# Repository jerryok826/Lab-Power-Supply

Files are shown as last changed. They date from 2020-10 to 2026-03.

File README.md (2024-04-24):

# Lab Power Supply
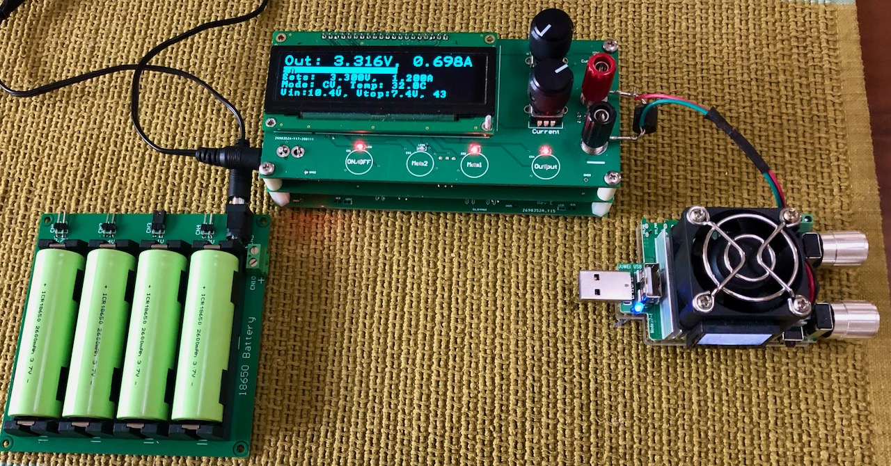
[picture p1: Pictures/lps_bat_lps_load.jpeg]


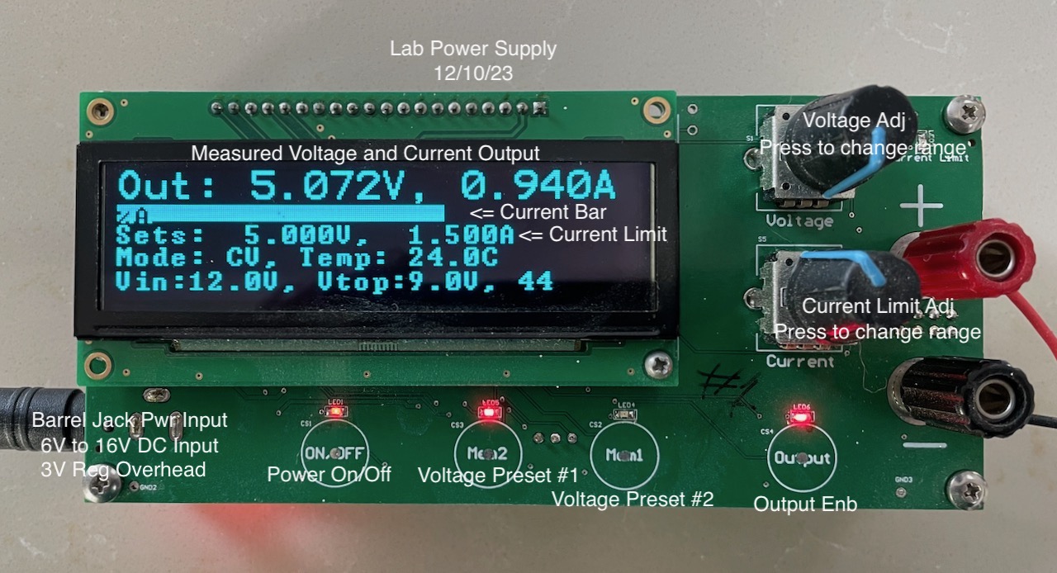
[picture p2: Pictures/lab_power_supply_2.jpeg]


## Project Description
I always thought that most laborary power supplies (LPS) take up to much bench space. This design is just 2.5 inches by 5.5 inches and runs off a wall wart or it can be powered from a lithium battery pack. The unit's specs are 0 to 15 volts output with a maximum output current of 1.5 amps. It has two output adjustable voltage presets with defaults of 5 and 3.3 volts. It has two rotary encoders, one for voltage control and the other for current limiting. Pressing an encoder button will change it's adjustement range. There is one additional button for output enable. The LPS can also be controlled remotely via USB using ModBus. There is also a realtime analog current bar graph on the oled display.

The control processor is a stm32f103c8t6, an Arm Cortex-M3 MCU with 64 Kbytes of flash memory and a 72 MHz CPU. The current code runs on libopencm3 and FreeRTOS. The display is a 256x128 OLED display. It is driven by uGui software. The unit is composed of two boards. The top board is the control and display board. The board below is the regulator board. The regulator board is composed of a low voltage drop linear regulator and a highly efficient switching regulator. Because of the combined efficiency of the switching and linear regulator not much of a heat sink is required. To reduce the noise generated by the switcher to a minimum, the switcher has large imput capacitors and a 3KHz loop pass filter on its output feeding the linear regulator. The switcher output voltage set to maintain a two voltage drop across the linear regulator.
### Project Status
The project is basically complete. I am working on converting the design to Kicad and STM32 IDE Cube. Also I'm thinking abouting redoing the display board with a RP2040 running MicroPython. This should make it easy for the end user to add their own features. For example, adding WIFI control support.

## Design Files
### Electrical Design Files
This project was initially designed with Altium Designer and is now being updated with Kicad 7.X The control software is C code runing on FreeRTOS.

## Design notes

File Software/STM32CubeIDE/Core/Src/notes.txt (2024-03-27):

notes.txt
~/STM32CubeIDE/workspace_1.14.0/lps_stm32f103RTC6_test1/Core/Src

cd ~/STM32CubeIDE/workspace_1.14.0/
tar -czvf lps_stm32f103RTC6_test1.tgz lps_stm32f103RTC6_test1
cd lps_stm32f103RTC6_test1/Core/Src

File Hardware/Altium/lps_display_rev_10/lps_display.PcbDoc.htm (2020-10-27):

Reporting Options

# File in Previous Format

Date | : | 7/23/2018
Time | : | 6:37:35 PM
Filename | : | C:\circuits\Projects\lab_power_supply\lab_pwr_supply.PcbDoc

Version | Warning

This file was generated by an earlier version of the software

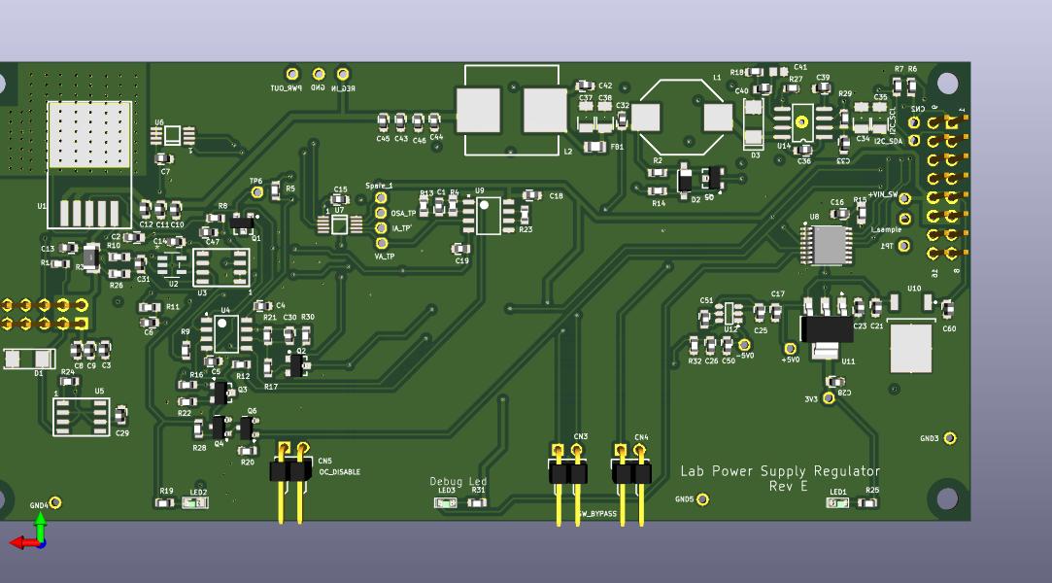
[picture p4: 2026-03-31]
Hardware/Kicad/lps_regulator/lps_regulator_rev_12.jpg

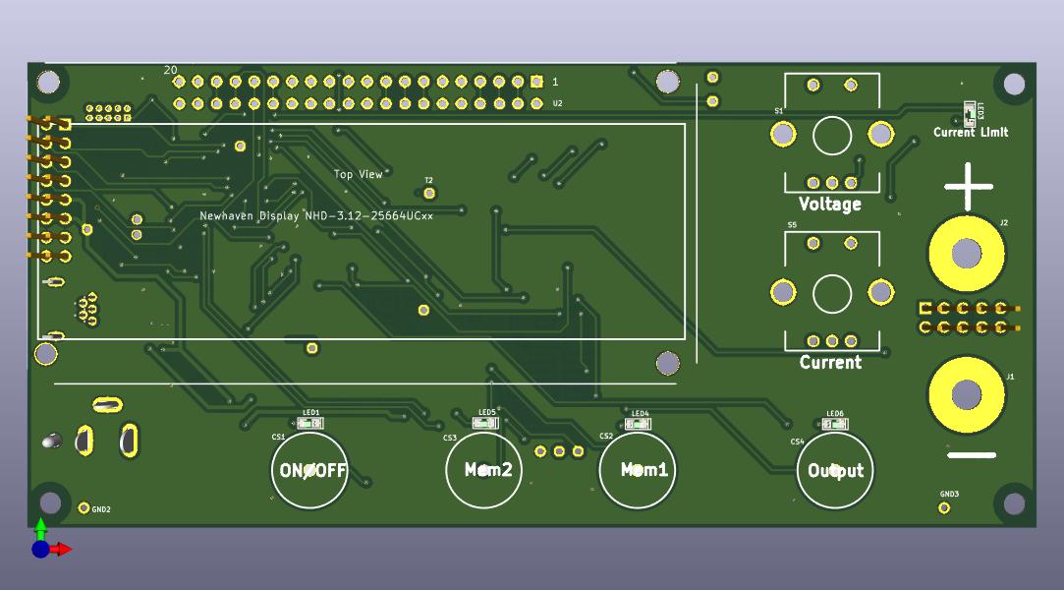
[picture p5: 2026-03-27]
Hardware/Kicad/lps_display/lps_display_rev_10.jpg

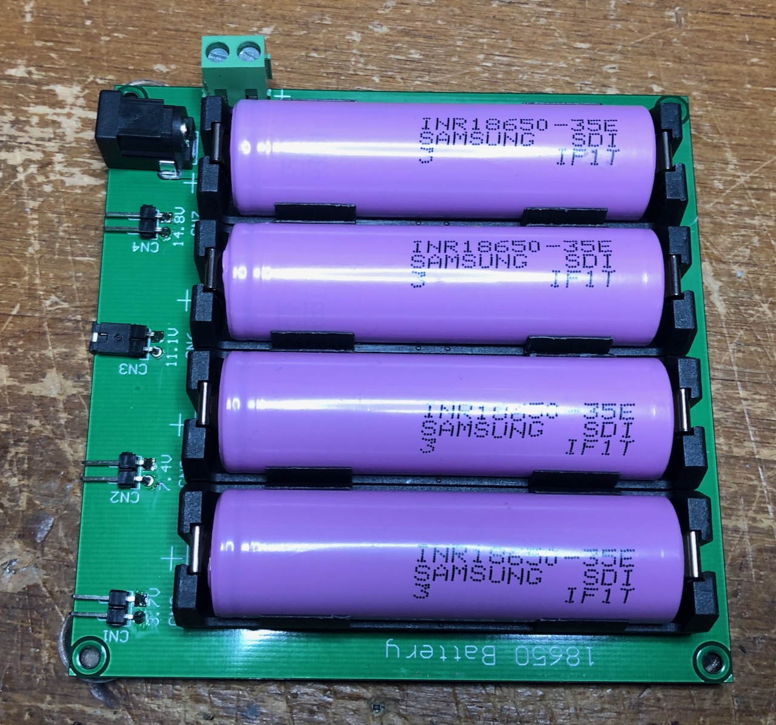
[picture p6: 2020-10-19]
Pictures/battery_pak.jpeg

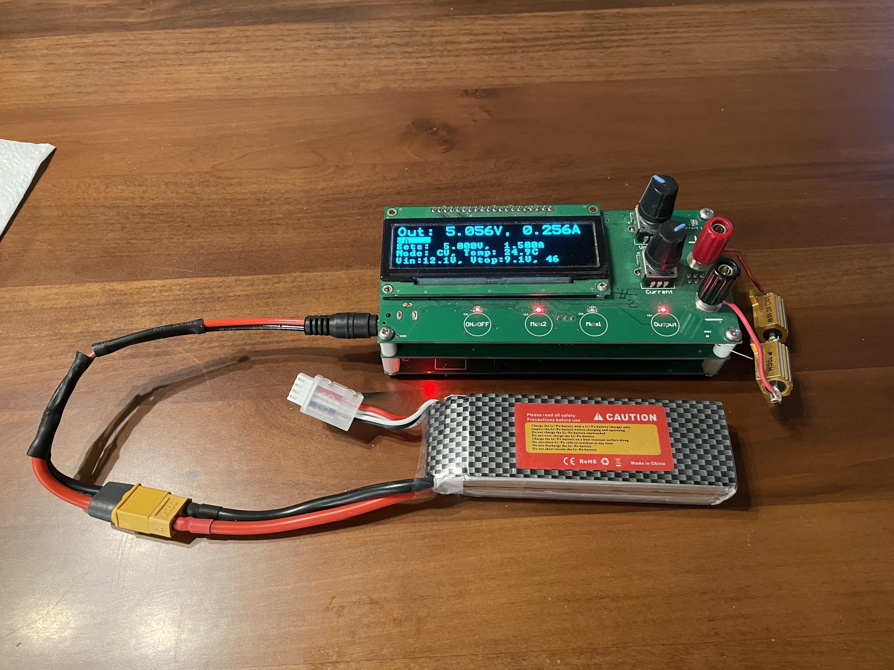
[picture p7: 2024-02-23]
Pictures/lps_bat_lps_load_2.jpeg

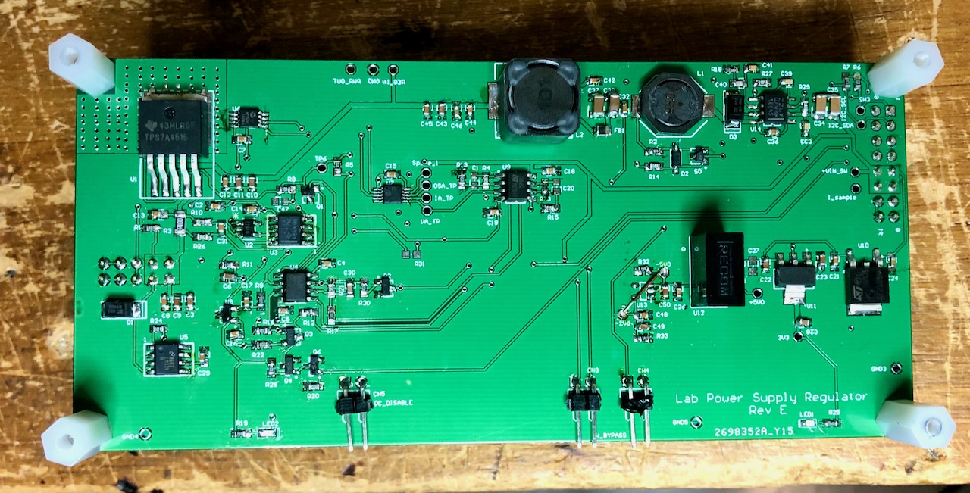
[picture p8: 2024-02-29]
Pictures/regulator_board.jpeg

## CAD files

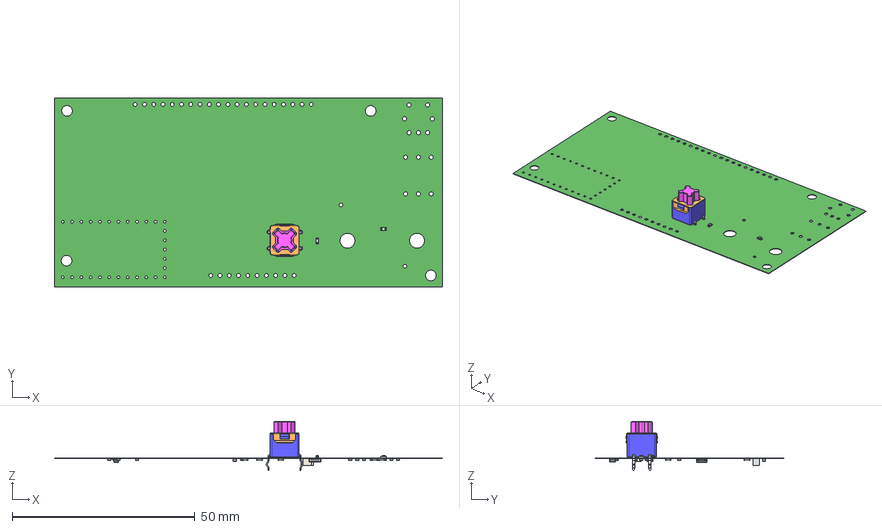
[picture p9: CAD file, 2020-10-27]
Hardware/Altium/lps_display_rev_10/lps_display.step
106.3 x 51.8 x 13.5 mm
Board
Resistor_0603 x 18
Resistor_0805
SKPFAA
SW3dPS-LED_SMD0603 x 2
SOT-23
Capacitor_0603 x 3
Extruded x 3
RES-1206

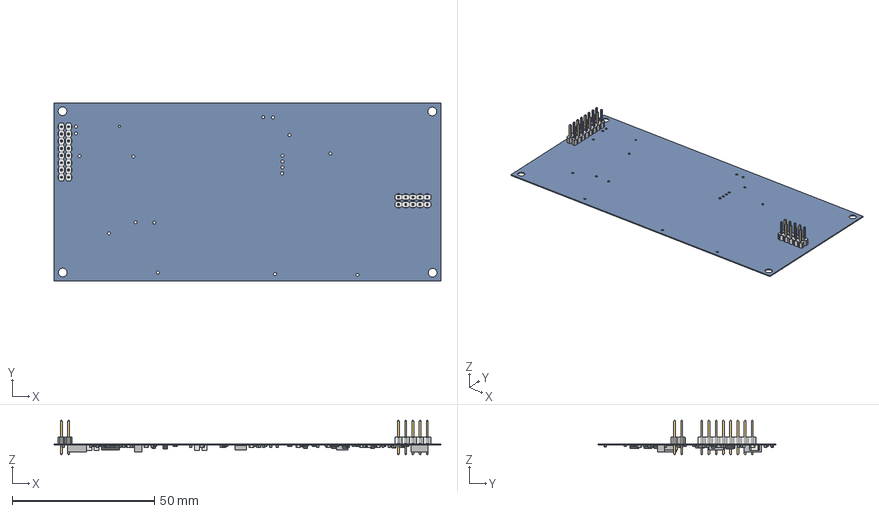
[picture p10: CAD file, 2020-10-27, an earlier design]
Hardware/Altium/lps_regulator_rev_11/asof.082420/lps_regulator_3.step
136.2 x 62.6 x 12.2 mm
Resistor_0603 x 30
Capacitor_0603 x 41
Extruded x 24
SOT-23 x 7
SOD123
SOT-223
HDR1x1 x 26
RES-1206
SW3dPS-LED_SMD0603 x 2

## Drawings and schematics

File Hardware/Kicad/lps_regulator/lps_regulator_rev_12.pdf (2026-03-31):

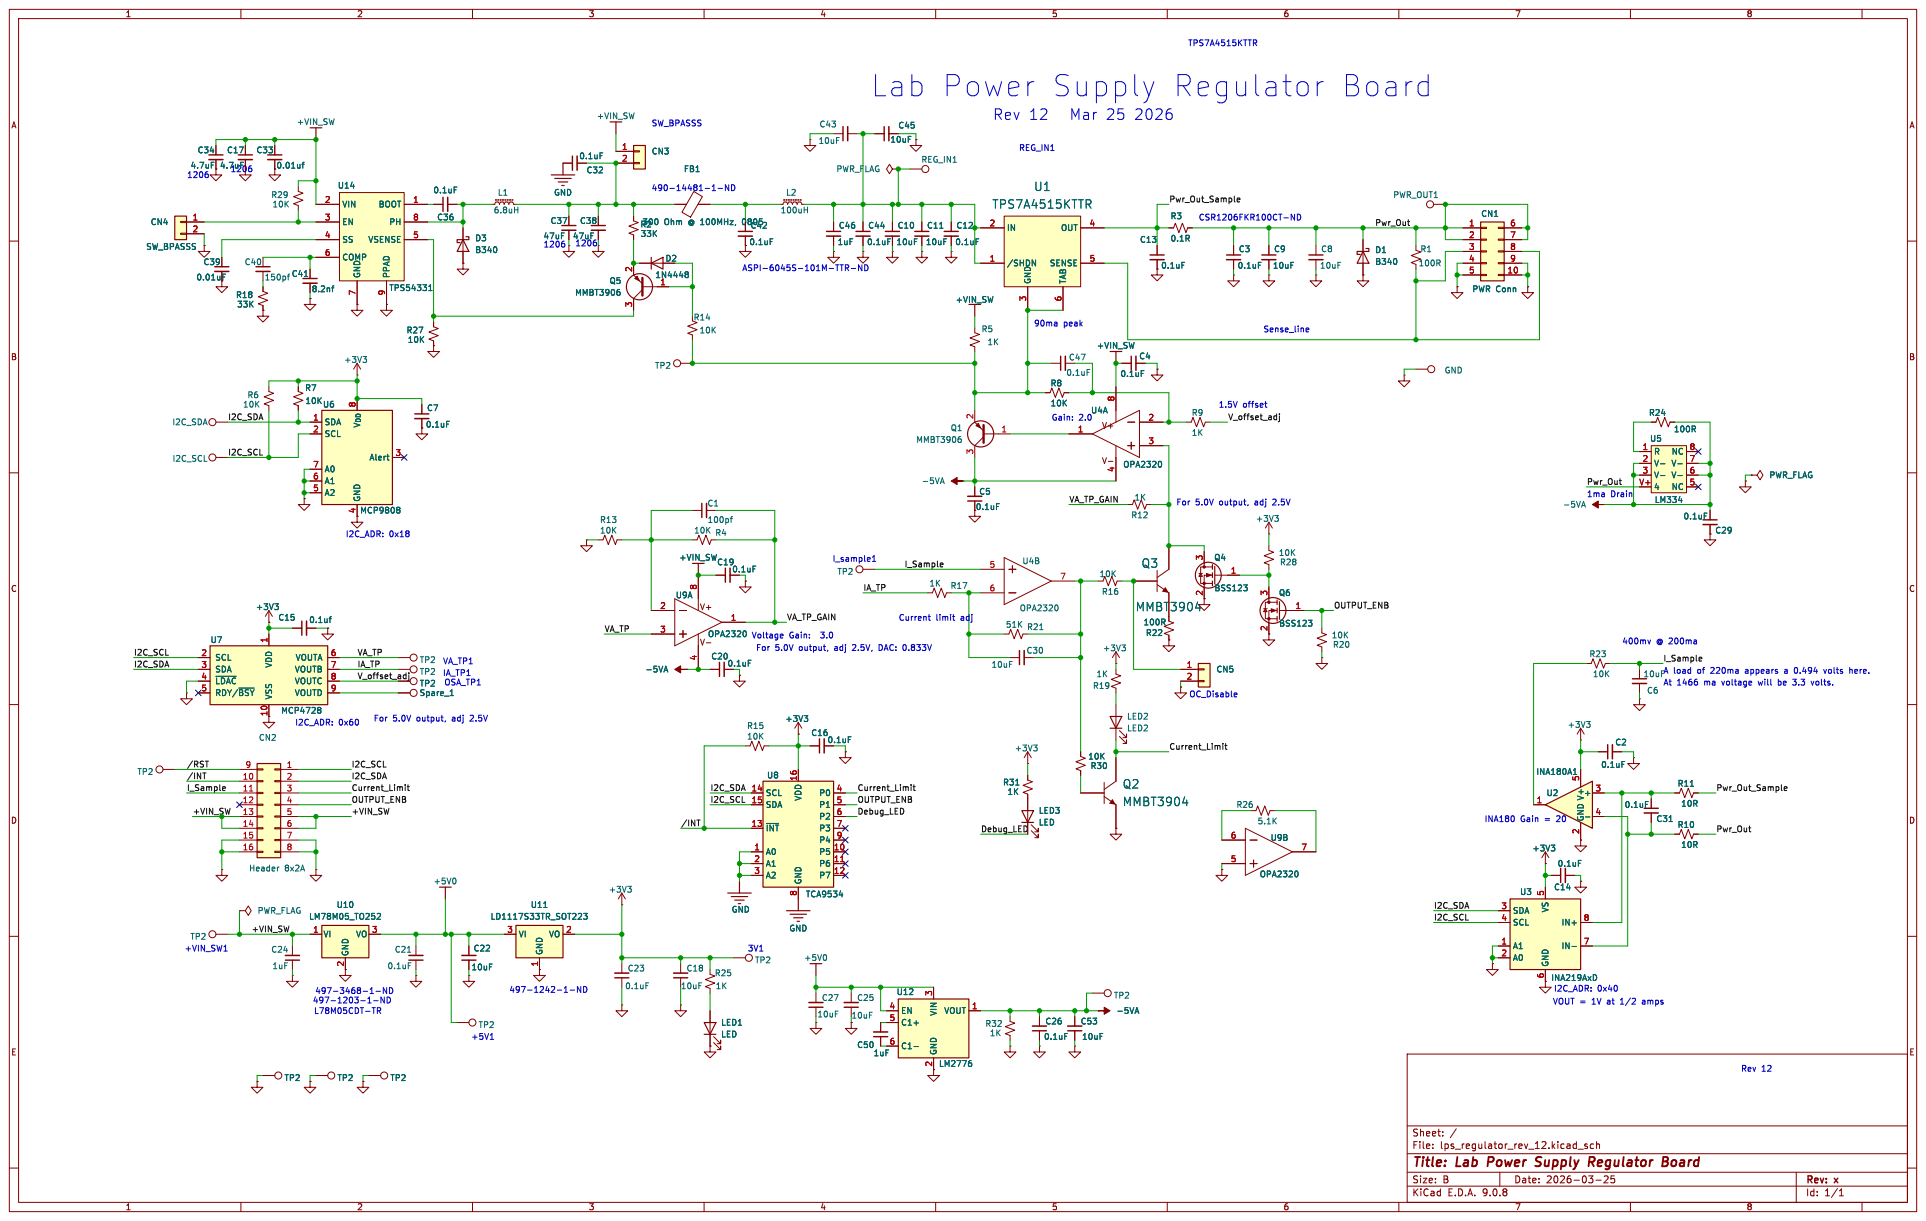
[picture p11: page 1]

For 5.0V output, adj 2.5V, DAC: 0.833V Lab Power Supply Regulator Board

3 2 U6 MCP9808 SDA 1 SCL 2 A0 7 A1 6 A2 5 V_{DD} 8 GND

1.5V offset For 5.0V output, adj 2.5V

1 VO 2 U7 MCP4728 SCL 2 SDA 3 ~{LDAC} 4 RDY/~{BSY} 5 VDD

1 VSS 10 VOUTA 6 VOUTB 7 VOUTC 8 VOUTD 9 U7 MCP4728 C24

1 VSS 10 VOUTA 6 VOUTB 7 VOUTC 8 VOUTD 9 TP2 TP2 TP2 U10

Id: 1/1 Title: Lab Power Supply Regulator Board

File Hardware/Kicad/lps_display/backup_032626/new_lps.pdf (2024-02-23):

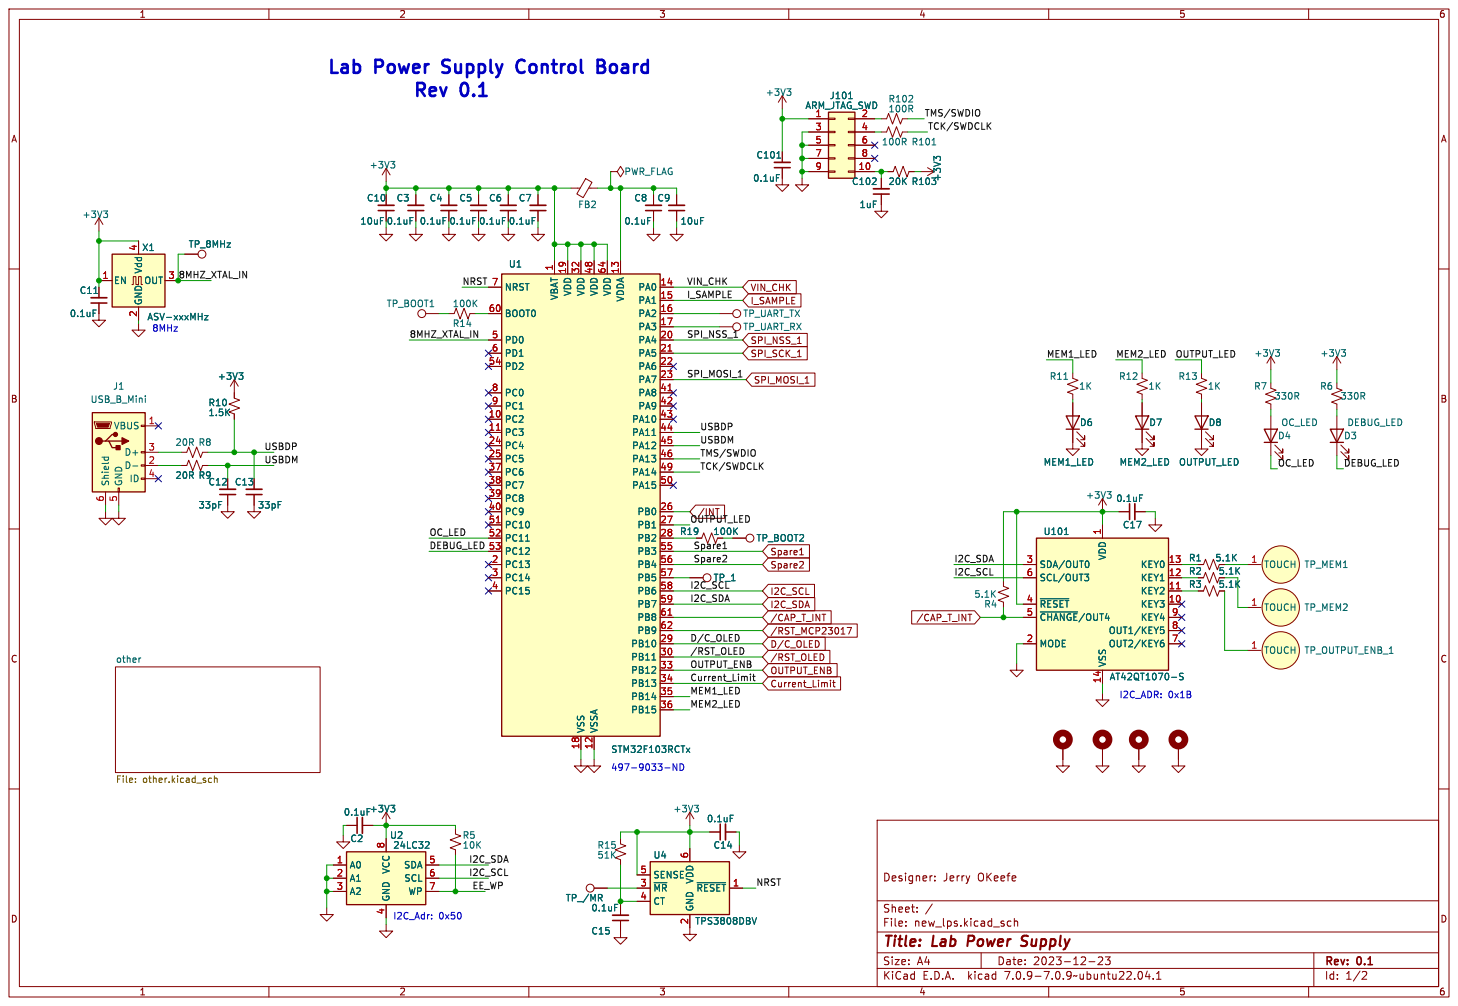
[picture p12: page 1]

Lab Power Supply Control Board

1 KEY3 10 KEY2 11 KEY1 12 KEY0 13 VSS 14 MODE 2 SDA/OUT0 3 ~{RESET} 4 ~{CHANGE}/OUT4 5 SCL/OUT3 6 OUT2/KEY6 7 OUT1/KEY5 8 KEY4 9 R1 5.1K R2 5.1K R3 5.1K TP_1 R19 100K TP_BOOT2 +3V3 20K R103 C101

1 PC2 10 PC3 11 VSSA 12 VDDA 13 PA0 14 PA1 15 PA2 16 PA3 17 VSS 18 VDD 19 PC13 2 PA4 20 PA5 21 PA6 22 PA7 23 PC4 24 PC5 25 PB0 26 PB1 27 PB2 28 PB10 29 PC14 3 PB11 30 VDD 32 PB12 33 PB13 34 PB14 35 PB15 36 PC6 37 PC7 38 PC8 39 PC15 4 PC9 40 PA8 41 PA9 42 PA10 43 PA11 44 PA12 45 PA13 46 VDD 48 PA14 49 PD0 5 PA15 50 PC10 51 PC11 52 PC12 53 PD2 54 PB3 55 PB4 56 PB5 57 PB6 58 PB7 59 PD1 6 BOOT0 60 PB8 61 PB9 62 VDD 64 NRST 7 PC0 8 PC1 9 C9

1 PC2 10 PC3 11 VSSA 12 VDDA 13 PA0 14 PA1 15 PA2 16 PA3 17 VSS 18 VDD 19 PC13 2 PA4 20 PA5 21 PA6 22 PA7 23 PC4 24 PC5 25 PB0 26 PB1 27 PB2 28 PB10 29 PC14 3 PB11 30 VDD 32 PB12 33 PB13 34 PB14 35 PB15 36 PC6 37 PC7 38 PC8 39 PC15 4 PC9 40 PA8 41 PA9 42 PA10 43 PA11 44 PA12 45 PA13 46 VDD 48 PA14 49 PD0 5 PA15 50 PC10 51 PC11 52 PC12 53 PD2 54 PB3 55 PB4 56 PB5 57 PB6 58 PB7 59 PD1 6 BOOT0 60 PB8 61 PB9 62 VDD 64 NRST 7 PC0 8 PC1 9 U1 STM32F103RCTx D7 MEM2_LED

1 KEY3 10 KEY2 11 KEY1 12 KEY0 13 VSS 14 MODE 2 SDA/OUT0 3 ~{RESET} 4 ~{CHANGE}/OUT4 5 SCL/OUT3 6 OUT2/KEY6 7 OUT1/KEY5 8 KEY4 9 U101 AT42QT1070-S

4 SDA 5 SCL 6 WP 7 VCC

2 ~{MR} 3 CT 4 SENSE 5 VDD

File: new_lps.kicad_sch Sheet: / Designer: Jerry OKeefe

Id: 1/2 Title: Lab Power Supply

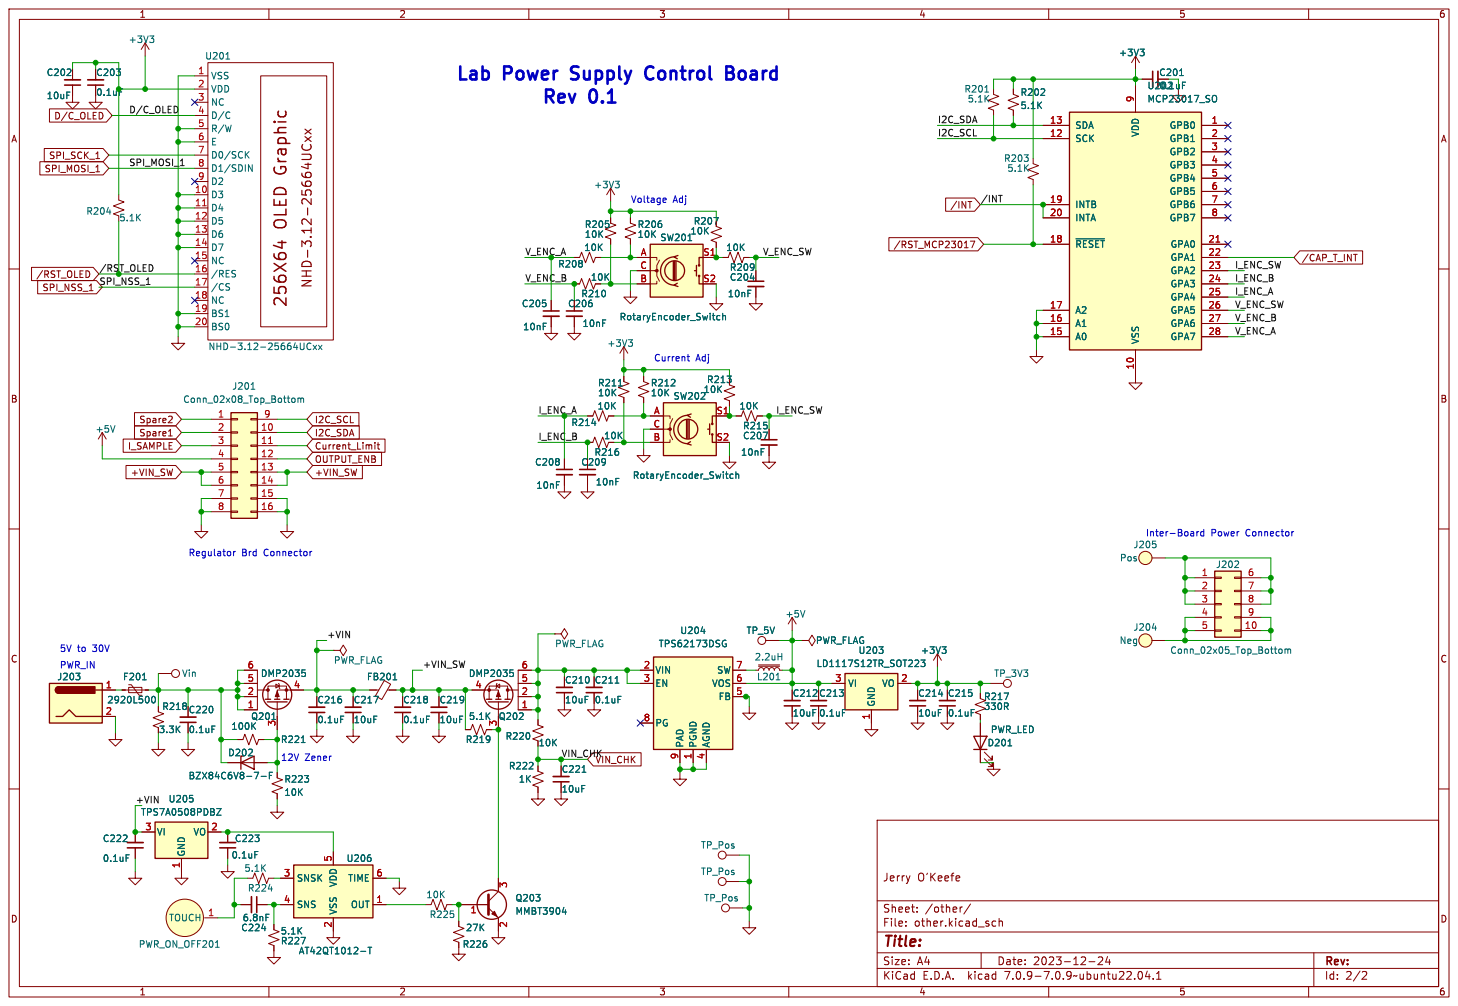
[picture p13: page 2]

VSS 1 D3 10 D4 11 D5 12 D6 13 D7 14 NC 15
/CS 17 NC 18 BS1 19 VDD 2 BS0 20 NC 3 D/C 4 R/W 5 E

Voltage Adj Current Adj PWR_IN

4 FB 5 VOS 6 SW 7 PG 8 PAD

Id: 2/2 Title: File: other.kicad_sch Sheet: /other/ Jerry O'Keefe

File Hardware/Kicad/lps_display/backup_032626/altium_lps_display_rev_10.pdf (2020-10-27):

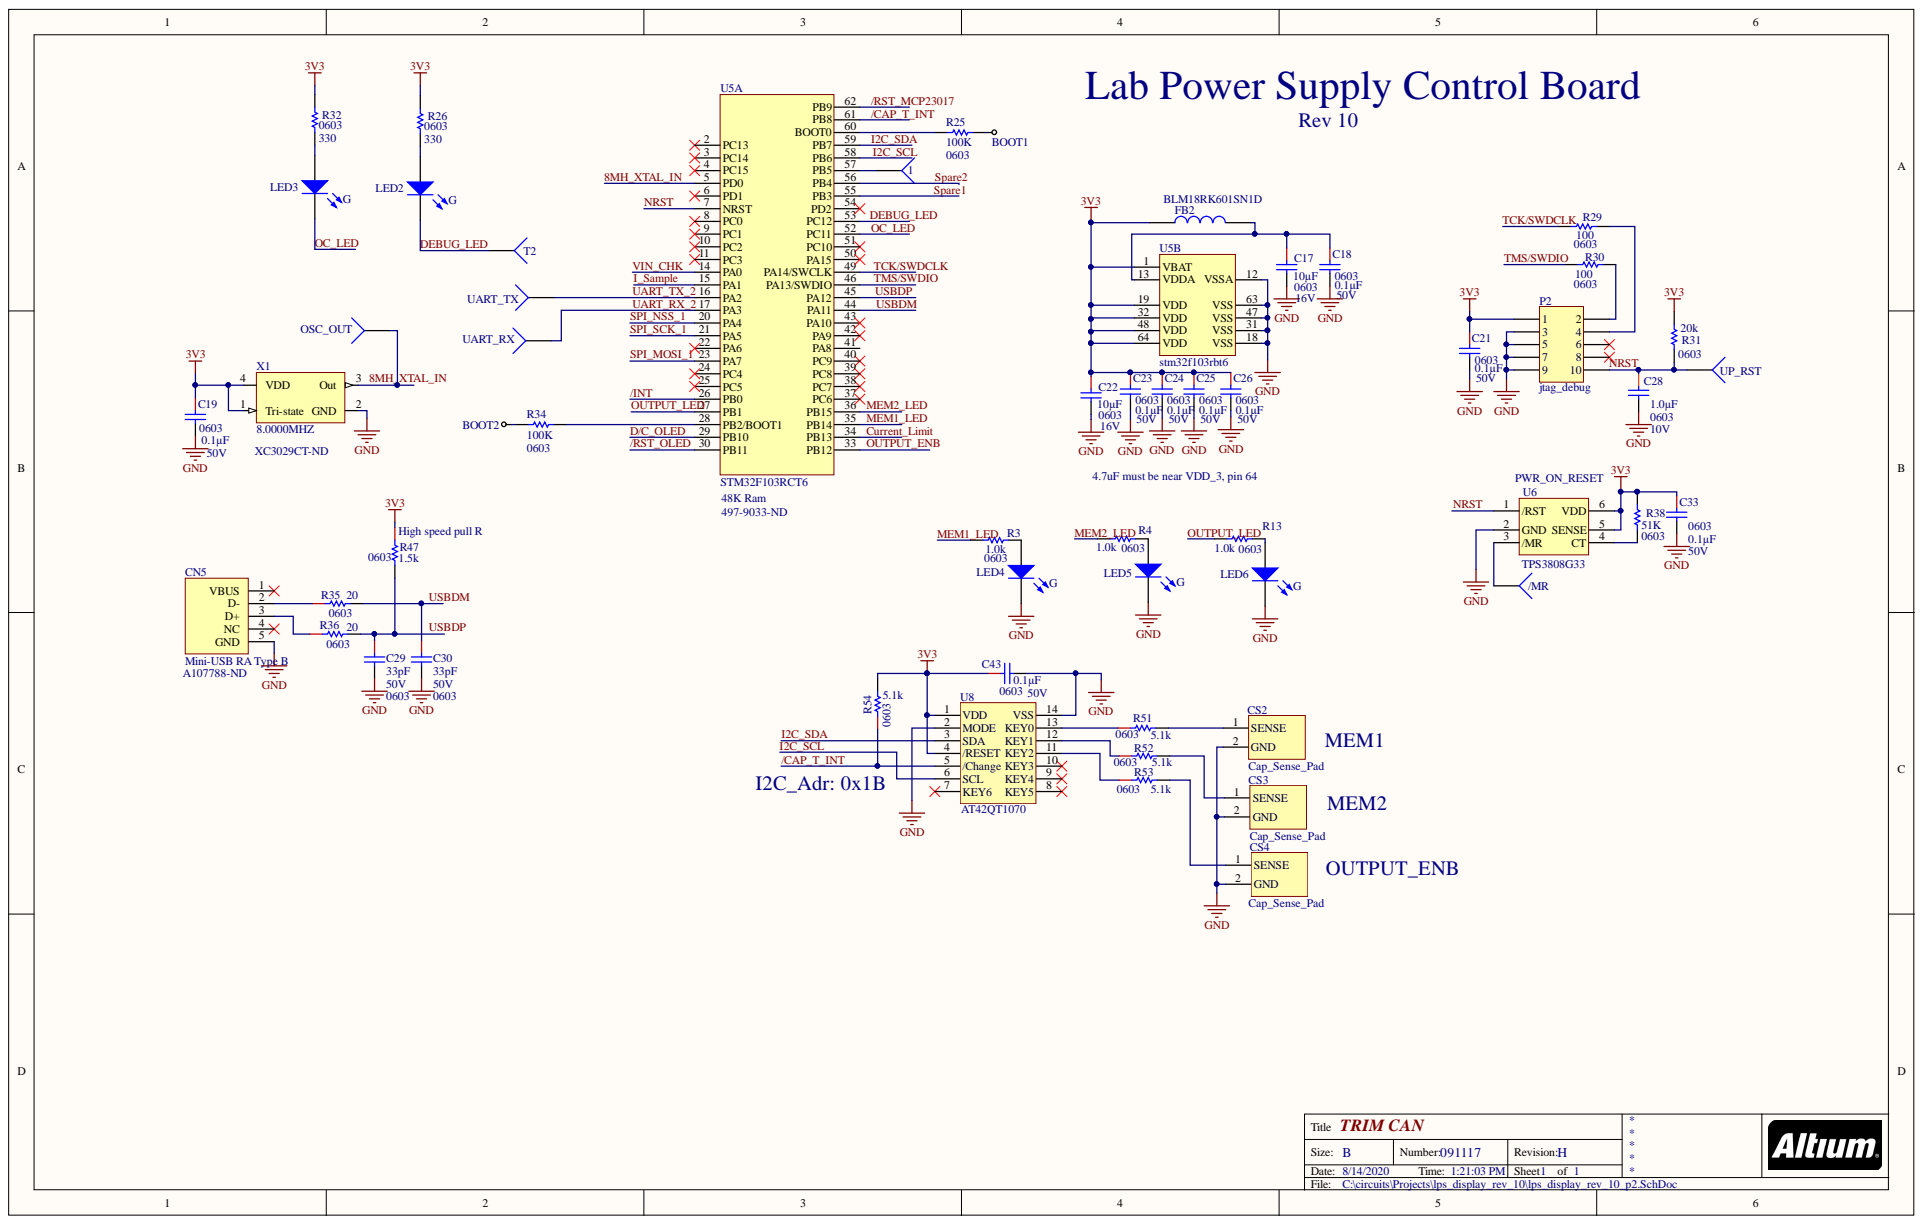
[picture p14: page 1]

Lab Power Supply Control Board

Ti tl e TRIM CA N | **** *

Size: B | Number : 0 9 1 1 1 7 | Revi s ion: H
Date: Ti me: | | Sheet 1 of 1
Fi le: lps_di splay_rev_10_p2.SchDoc

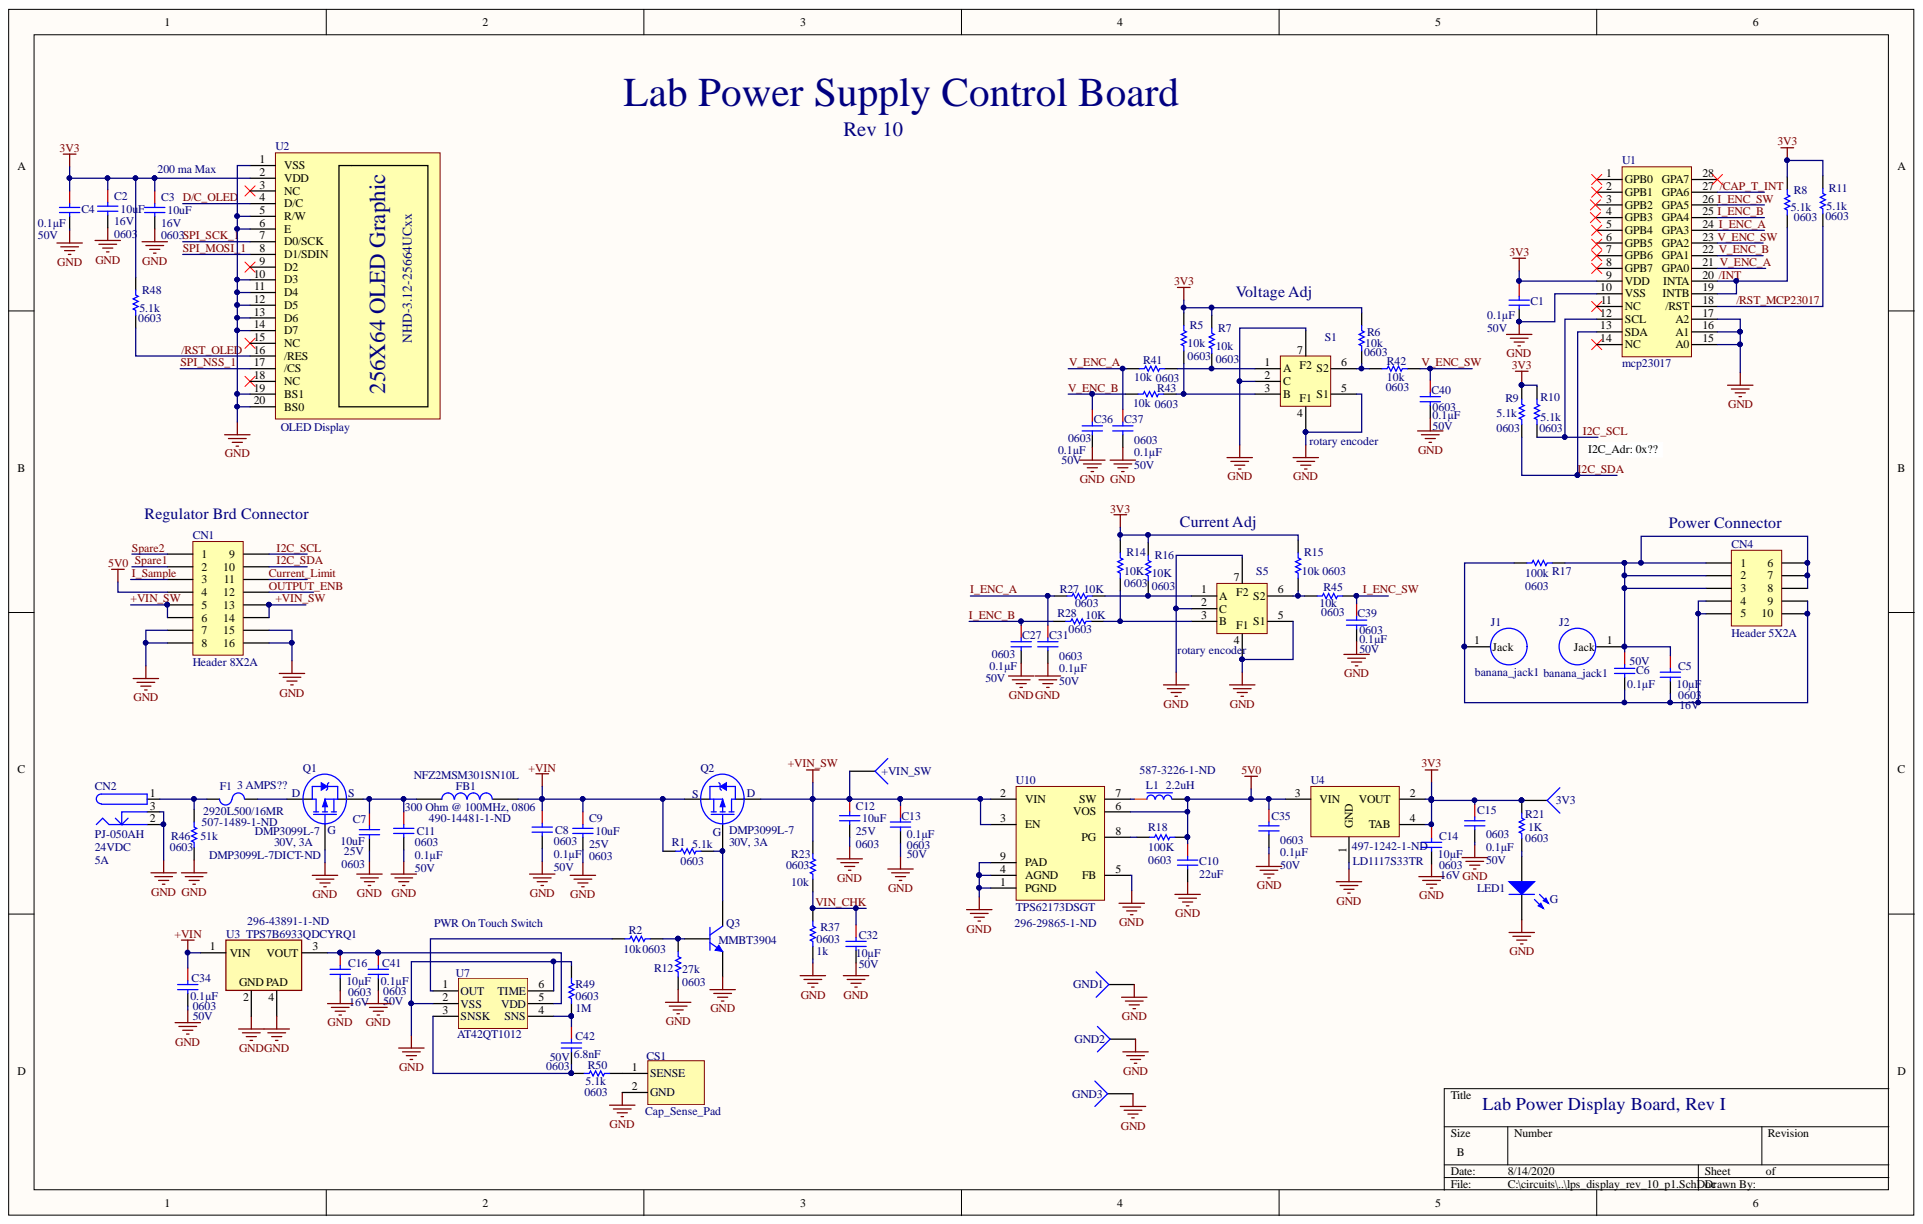
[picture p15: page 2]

Lab Power Supply Control Board

Title
Lab Power Display Board, Rev I

Size B | Number | Revision

Date: 8/14/2020 | Sheet of
File: C:\circuits\..\lps_display_rev_10_p1.SchDDocrawn By:

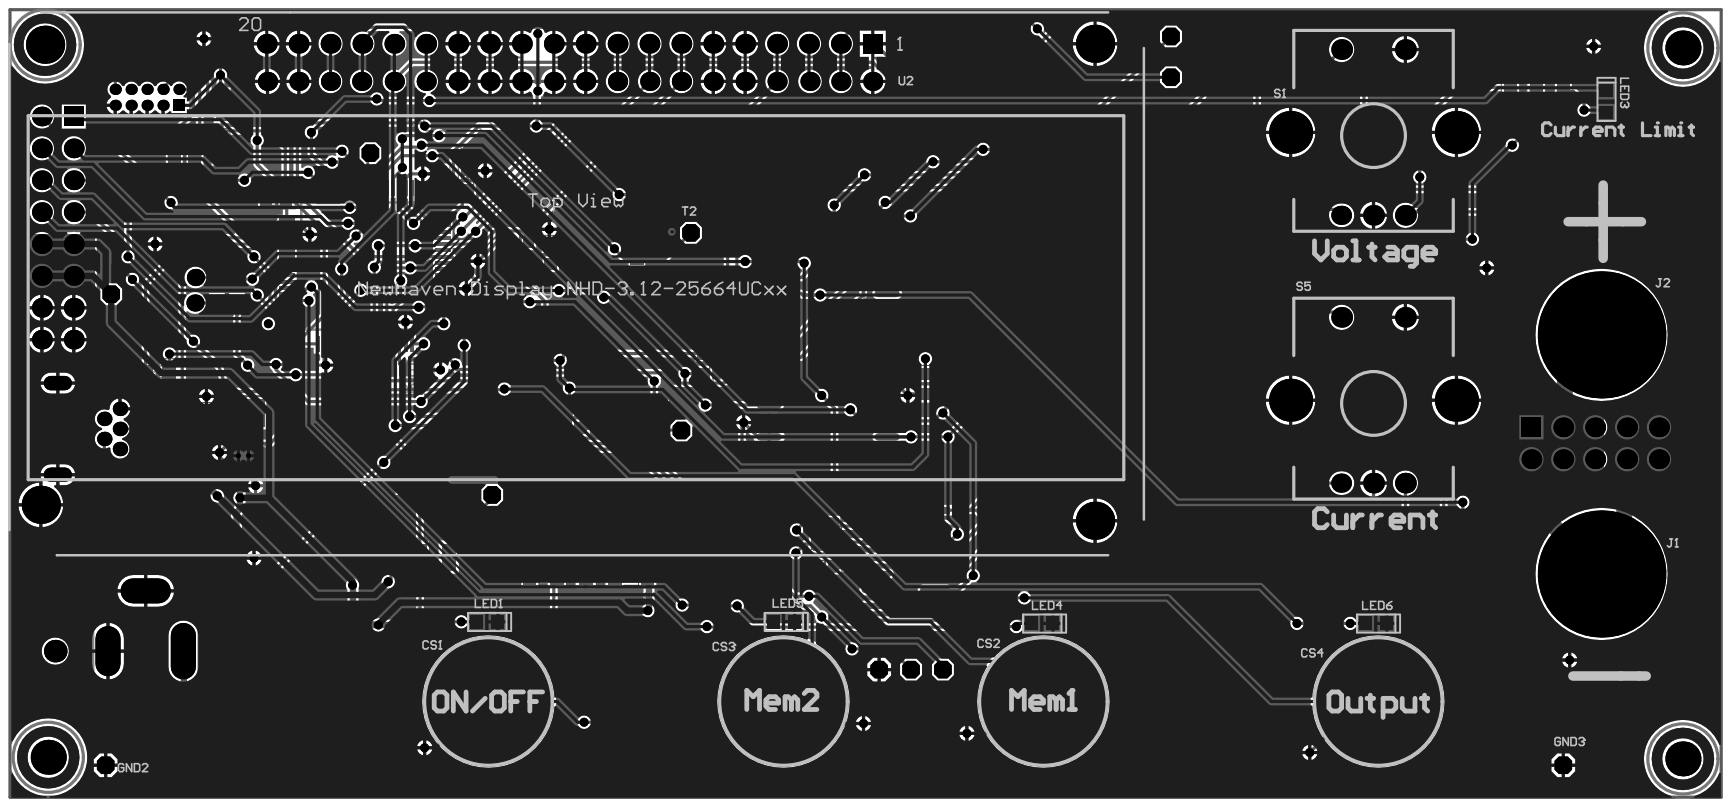
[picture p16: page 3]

Description | Designator | LibRef | Manufacturer Manufacturer Quantity | Supplier 1 | Supplier CurreSupplier Order S upplier Part NSupplie r Stock Supplier SubtSupplier Unit Price 1
Test Point WhBOOT 1,BOOTTestPoint-PC-W | 2 | Digi-Key | 36-5002-ND
0.1uF0603 50C1,C4,C6,C8CAPCER0.1UF50V10%X7R0603 | 27 | Digi-Key | 399-5089-1-ND,311-1343-1-ND
10UF0603 16C2,C3,C5,C7CAPCER10UF16V20%X5R0603 | 10 | Digi-Key | 490-7201-1-ND
CAP CER 22UFC10 | CMP-001-0737-02 | 1
1uF0603 10VC28 | CAP CER 1UF 10V 10% X5R 0603 | 1 | Digi-Key | 399-3118-1-ND
CAP CER 33PFC29,C30 | CMP-0 07-0143-08 | 2
Header, 8-PinCN1 | CMP-001-0325-01 | 1
Power BarrelCCN2 | CMP-001-0507-01 | 1
Header, 5-PinCN4 | CMP-001-0310-01 | 1
Mini-USB RA TCN5 | CMP-001-0449-01 | 1
CS1,CS2,CS3Cap_Sense_Pad | 4
PTC RESET FUF1 | CMP-001-0852-01 | 1
40 OHM 0805FB1 | FERRITE 40 OHM 1.5A 0805 | 1 | Digi-Key | 240-2389-1-ND
FERRITE 120 FB2 | FERRITE BEAD 120 OHM 0603 1LN | 1 | Digi-Key | 445-2170-1-ND
J1, J2 | banana_jack1 | 2
FIXED IND 2.2L1 | CMP-001-0772-02 | 1
0603 SMD LEDLED1, LED2, LE0603 L D | 6
P2 | jtag_debug | 1
DMP3099L-7Q1,Q2 | DMP3099L-7 | 2 | Digi-Key | DMP3099L-7DICT-ND
MMBT3904 NPQ3 | MMBT3904 | 1 | Digi-Key | MMBT3904WT1GOSCT-ND
4.7K0603 | R1, R2, R5, R6RES4 .7KOHM1/10W5%0603SMD | 23 | Digi-Key | P4.7KGCT-ND
1.0K0603 | R3, R4, R13, RRES 1KOH M1%1/10W0603 | 10 | Digi-Key | RMCF0603FT1K00CT-ND
100K0603 | R18,R25,R34RES 100KOHM1% 1/10W 0603 | 3 | Digi-Key | 311-100KHRCT-ND
100 0603 | R29,R30 | RES 100 OHM1% 1/10W 0603 2017 | 2 | Digi-Key | 541-2975-1-ND
10K0603 | R31 | RES 10K OHM 1/10W 1% 0603 SMD | 1 | Digi-Key | P10.0KHCT-ND
Res Thick FilmR35,R36 | CMP-001-0711-04 | 2
RES 1.54KOHR47 | CMP-007-0337-12 | 1
ERJ3EKF5101R51,R52,R53CMP-0 01-0749-04 | 4
S1,S5 | rotary encoder | 2
I2C 16 bit ExpU1 | mcp23017 | 1
U2 | OLED Display | 1
TPS7B6933QDU3 | R-78E5.0-0.5 | 1
3.3 volt fixed reU4 | LD1117S33 | 1 | Digi-Key | 497-1242-1-ND
stm32f103rbt6U5 | stm32f103rbt6 | 1
TPS3808G33 | U6 | TPS3808G33 | 1

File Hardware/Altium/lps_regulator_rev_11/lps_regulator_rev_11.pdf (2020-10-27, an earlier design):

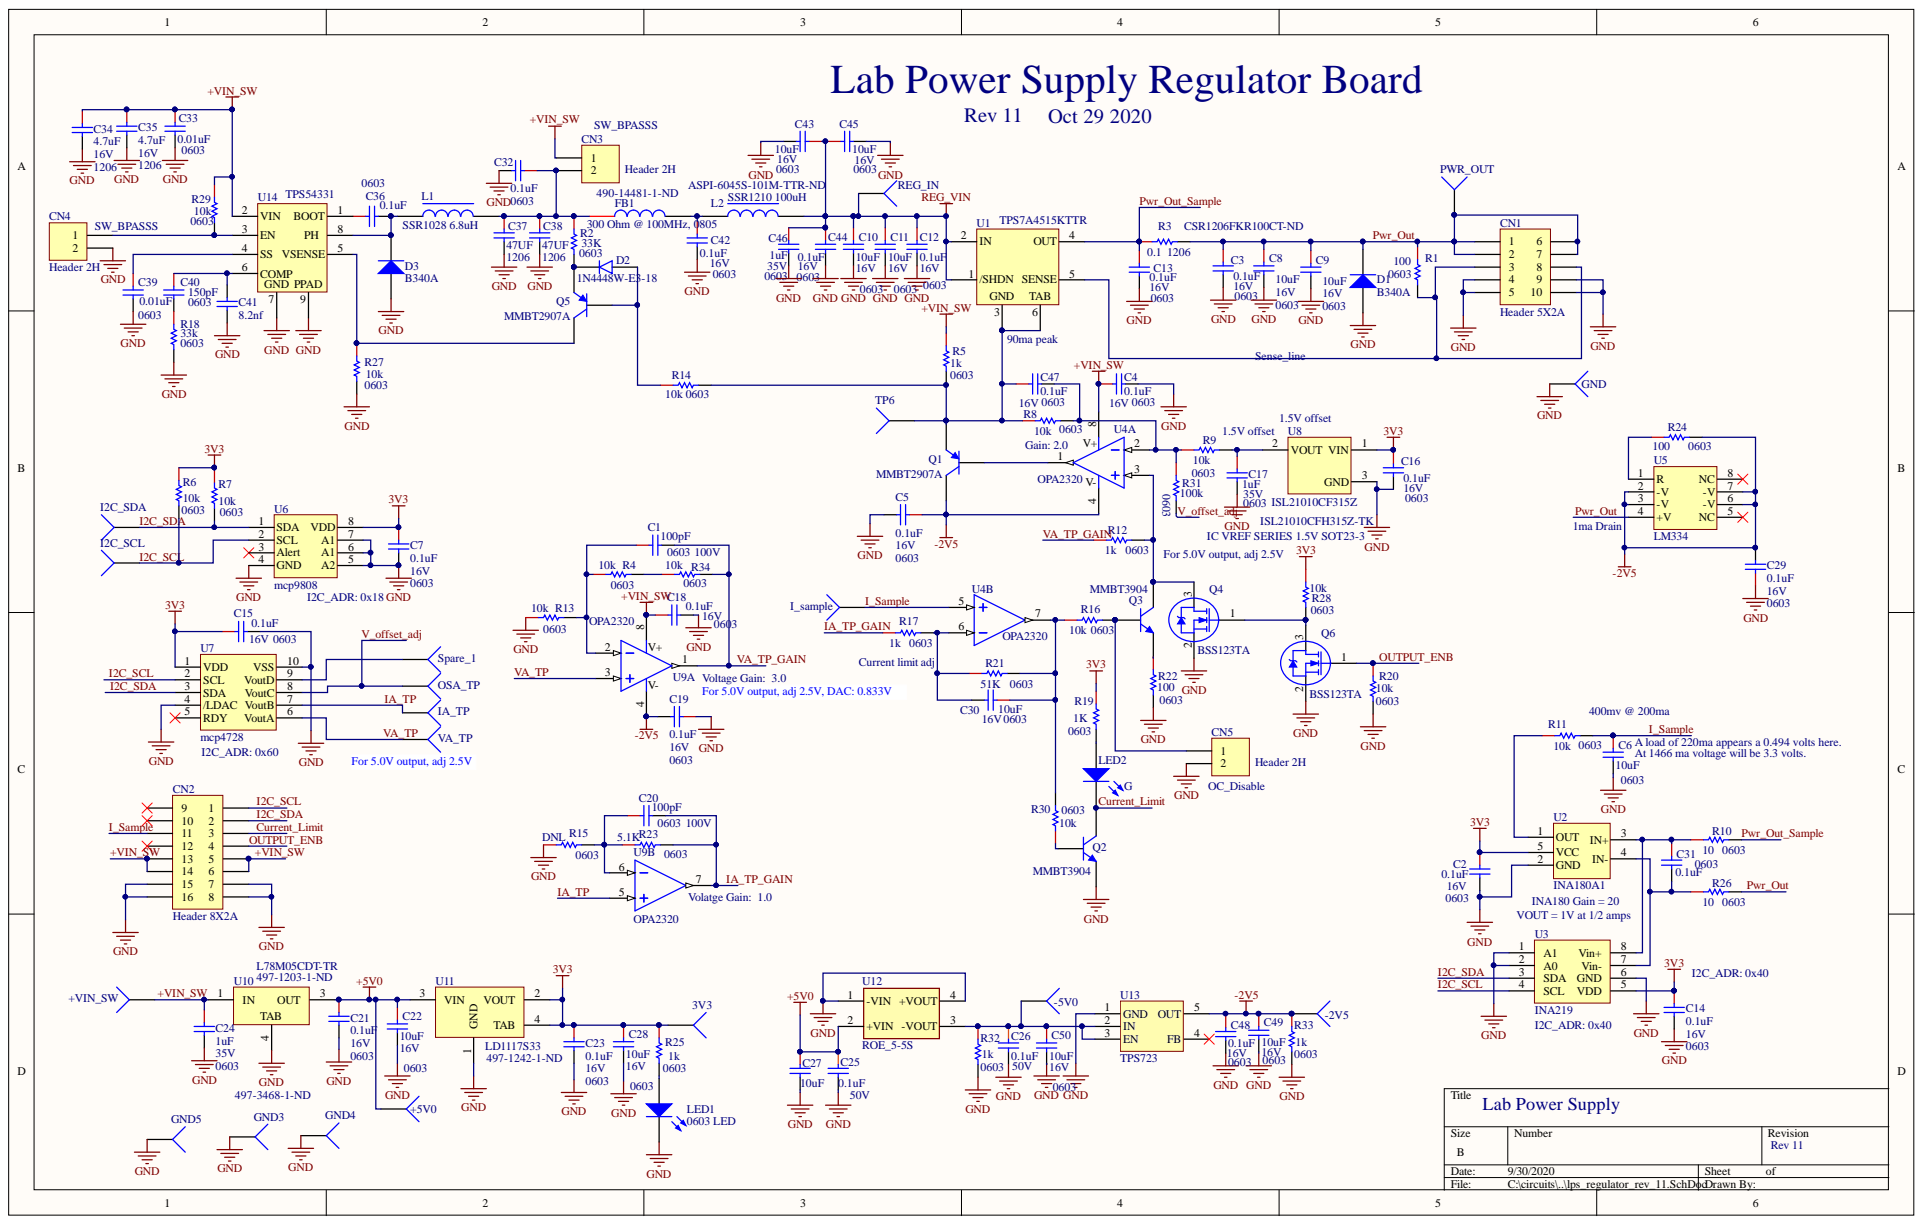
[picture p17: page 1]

Lab Power Supply Regulator Board

V+ | U4A | GND

RDY 5 VoutA SCL 2 SDA 3 | 6 VoutB 7 VoutC 8 VoutD 9 VSS 10

/LDAC 4 | | IA_TP

A load of 220ma appears a 0.494 volts here.
At 1466 ma voltage will be 3.3 volts.

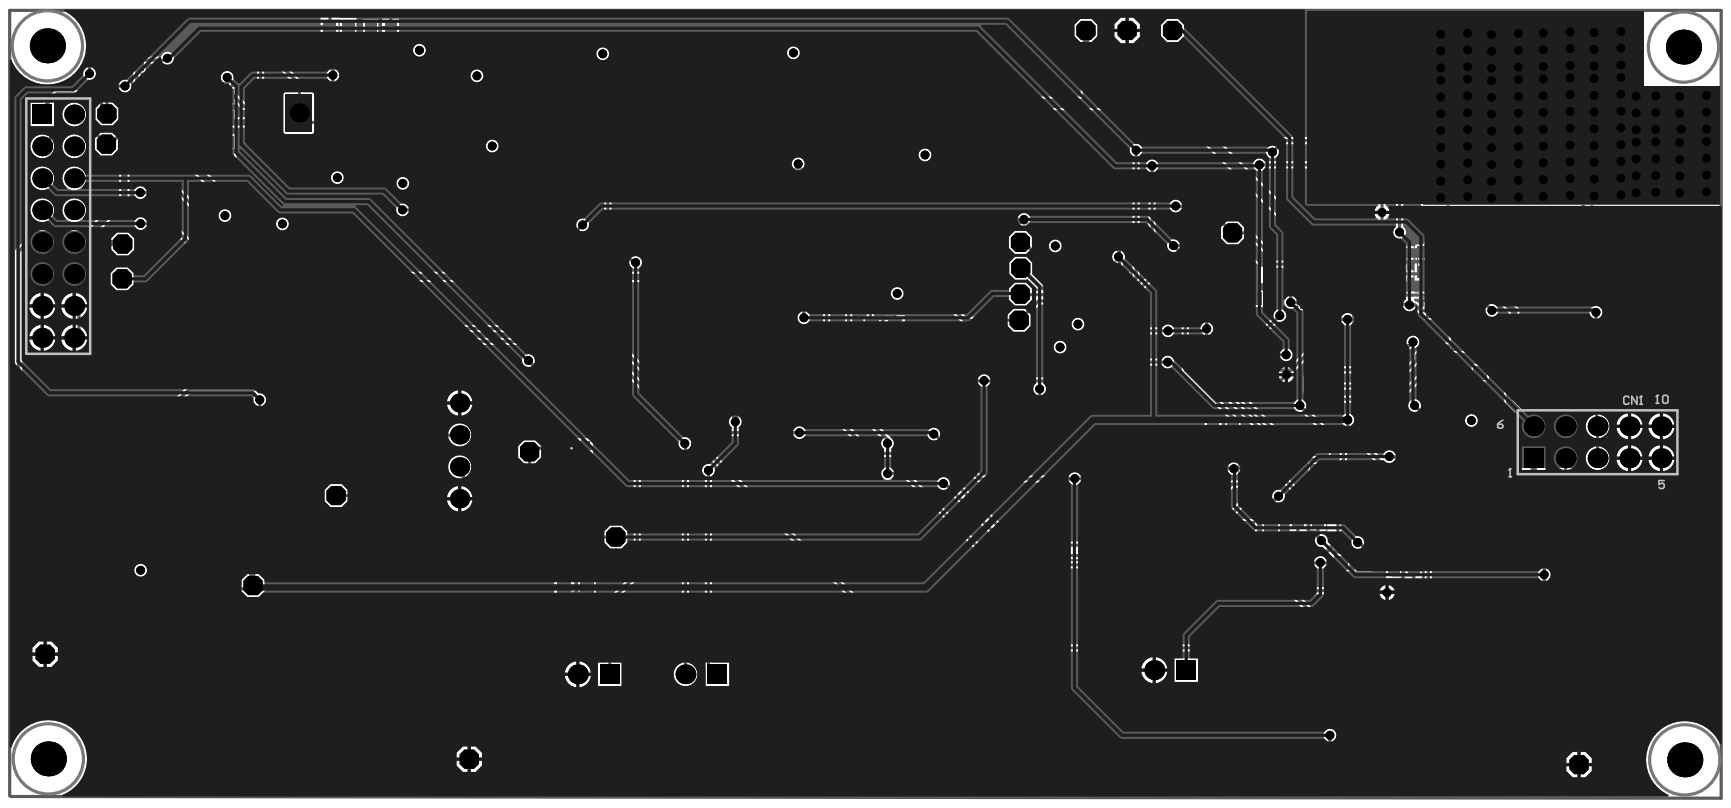
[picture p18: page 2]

Comment | Description | Designator | Footprint | LibRef | Quantity
TestPoint_BLK | Test Point - Black | -2V5, -5V0, +5V0, +VTestPoin t-T H 42 mil | CMP -005- 0210- 0 1 | 19
100pF | CAP CER 100PF 50V 5%C1, C20 | CAPC0603(1608)_N | CMP-007-0074-08 | 2
0.1uF | CAP CER 0.1UF 16V 10%C2, C7, C13, C18, C19, CAP C0603(1608) _M | CMP-007-0042-08 | 9
0.1uF | CAP CER 0.1UF 16V 10%C3, C4, C5, C12, C14, CA PC0603(1608)_ N | C MP-007- 0042- 08 | 13
10uF | CAP CER 10UF 16V X C6, C8, C9, C10, C11, CA PC0603(1608)_ N | C MP-001- 0603-12 | 11
1uF | CAP CER 1UF 35V 10%C17, C24, C46 | CAPC0603(1608)_M | CMP-007-0109-08 | 3
0.1uF | 0.1uF 0805 50V | C25, C26 | CAPC0805(2012)_N | CAP CER 0.1UF 50V | 10% | 2
10uF | 10UF 0805 16V | C27 | CAPC0805(2012)_M | CAP CER 10UF 16V 10% | 1
10uF | CAP CER 0.1UF 16V 10%C30 | CAPC0603(1608)_M | CMP-007-0042-08 | 1
0.01uF | CAP CER 0.01uF 50V C33, C39 | CA PC0603(1608)_ N | CMP-007-0028-08, CMP | 2
4.7uF | CAP CER 4.7UF 50V 10%C34, C 35 | CAPC1206(3216)_N | CMP-007-0147-08 | 2
47UF | CAP CER 47UF 25V 1206 C37, C38 | CAPC1206(3216)_L | CMP-001-0623-11 | 2
150pF | CAP CER 1UF 35V 10%C40 | CAPC0603(1608)_M | CMP-007-0109-08 | 1
8.2nf | CAP CER 820PF 50V XC 41 | CAPC1608X87X35ML15CMP-001-0751-01 | 1
Header 5X2A | Header, 5-Pin, Dual rowCN1 | HDR2X5_CEN | CMP-001-0310-01 | 1
Header 8X2A | Header, 8-Pin, Dual rowCN2 | HDR2X8_CEN | CMP-001-0325-01 | 1
Header 2H | Header, 2-Pin, Right ACN3, C N4, CN5 | HDR1X2H | CMP-001-0287-01 | 3
B340A | DIODE SCHOTTKY 60VD 1, D3 | DO-214AC | CMP-001-0130-02 | 2
1N4448W-E3-18 | Diodes - General PurpD2 | S OD123 | CMP-001-0983-02 | 1
300 Ohm @ 100MHz, | 0805 600 Ohms @ 100MHzF B1 | RESC 0805(2012)_N | C MP-007- 0197-02 | 1
SSR1028 6.8uH | INDUCTOR 6.8uH SMDL1 | SRU1028 | CMP-001-0686-01 | 1
SSR1210 100uH | INDUCTOR 100uH 2.2AL2 | SRR1210 | CMP-001-0686-01 | 1
0603 LED | 0603 SMD LED | LED1 | SM-LED-0603 | CMP-001-0009-04 | | 1
G | 0603 SMD LED | LED2 | SM-LED-0603 | 0603 LED | | 1
MMBT2907A | PNP General Purpose | Q1, Q5 | SOT23 | CMP-012-0075-02 | | 2
MMBT3904 | NPN General Purpose Q 2, Q3 | SOT23 | MMBT3904 | 2
BSS123TA | MOSFET N-CH 100V 170MA Q4, Q6 | SOT23-3L | CMP-012-0021-01 | 2
100 | RES 100 OHM 1% 1/10WR1, R23, R24 | RESC0603(1608)_N | CMP-007-0349-12 | 3
10K | RES 10K OHM 1/10W R2, R5, R6, R7, R8, R9, R10, R11, R14, R20, R26, R27, R28, R29 RESC0603(1608)_M | CMP-007-0359-12 | 14
0.33 | RES 0.33 OHM 1% 1/4WR3 | RESC1206(3216)_N | CMP-007-0323-14 | 1
10k | RES 10K OHM 0.1% 1/10W R4, R13, R34 | RESC0603(1608)_L | CMP-007-0357-12 | 3
1.0K | RES 1K OHM 1% 1/10WR12, R15, R16, R17, | R19, R22, R25, R30, R31, R32, R33 RESC0603(1608)_M | CMP-007-0404-12 | 11
33K | RES 33K OHM 1/10W R18 | RESC0603(1608)_N | CMP-007-0480-12 | 1
100K | RES 100K OHM 1% 1/10W R21 | RESC0603(1608)_M | CMP-007-0353-12 | 1
TPS7A4515KTTR | TPS7A4515KTTR, lineU1 | TPS7A4515KTTR | TPS7A4515KTTR | 1
INA180A1 | | U2 | SOT-23-5_MC | INA180A1 | | 1
INA219 | Current Monitor IC | U3 | INA219 | INA219 | | 1
OPA2320 | Dual Single Supply RaU4, U 9 | SOIC-8_NoPad | CMP-006-0027-01 | 2
LM334 | LM334, Current sourceU5 | LM334 | LM334 | 1
mcp9808 | | U6 | 8MSOP | mcp9808 | | 1
mcp4728 | MCP4728 | U7 | MCP4728 | mcp4728 | | 1
ISL21010CF315Z | | U8 | SOT23 | ISL21010CF315Z | | 1

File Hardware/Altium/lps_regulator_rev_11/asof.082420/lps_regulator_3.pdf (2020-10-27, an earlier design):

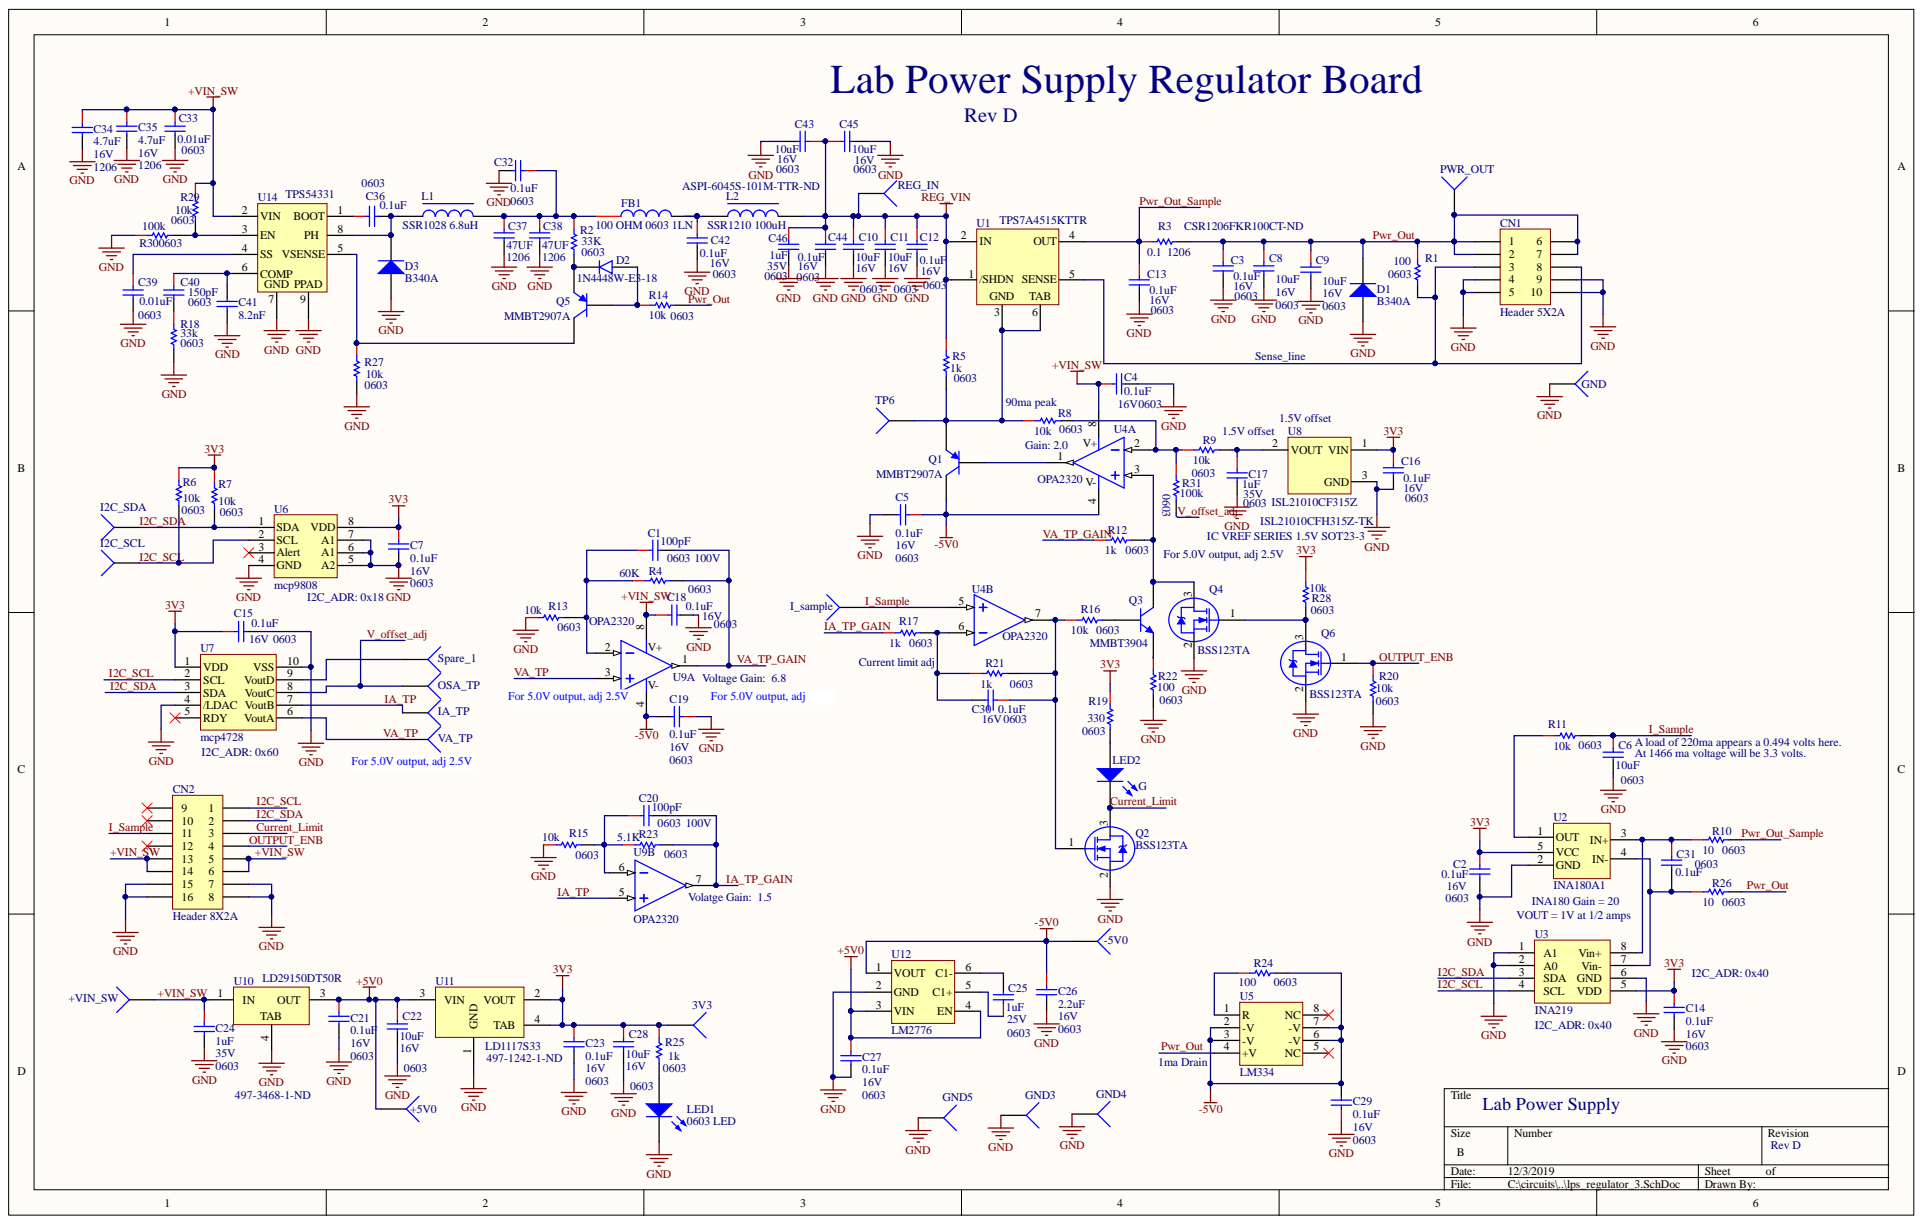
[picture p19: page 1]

Lab Power Supply Regulator Board

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

Comment | Description | Designator | Footprint | LibRef | Quantity
TestPoint_BLK | Test Point - Black | -5V0, +5V0, +VIN_SWTestPoint-TH 42mil | CMP-0 05-0210-01 | 18
100pF | CAP CER 100PF 50V 5C1,C20 | CAPC0603(1608)_N | CMP-007-0074-08 | 2
0.1uF | CAP CER 0.1UF 16V 1C2, C, C13,C18, C19CAPC0603(1608)_M | CMP-007-0042-08 | 10
0.1uF | CAP CER 0.1UF 16V 1C3, C4, C5,C12, C14,CAPC0603(1608 )_N | CMP-007-0 042-08 | 12
10uF | CAP CER 10UF 16V X5C6, C8, C9, C10, C11,CAPC0603(1608 )_N | CMP-001-0603-12 | 9
1uF | CAP CER 1UF 35V 10%C17,C24,C25,C46 | CAPC0603(1608)_M | CMP-007-0109-08,CM | 4
2.2uF | CAP CER 2.2UF 16V 1C26 | CAPC0603(1608)_M | CMP-007-0114-08 | 1
0.01uF | CAP CER 0.01uF 50V | C33, C39 | CAPC0603(1608)_N | CMP-0 07-0028-08,CM | 2
4.7uF | CAP CER 4.7UF 50V 1C34,C35 | CAPC1206(3216)_N | CMP-007-0147-08 | 2
47UF | CAP CER 47UF 25V 12C37, C38 | CAPC1206(3216)_L | CMP-001-0623-11 | 2
150pF | CAP CER 1UF 35V 10%C40 | CAPC0603(1608)_M | CMP-007-0109-08 | 1
8.2nF | CAP CER 820PF 50V X7C41 | CAPC1608X87X35ML1CMP-001-0751-01 | 1
Header 5X2A | Header, 5-Pin, Dual roCN1 | HDR2X5_CEN | CMP-001-0310-01 | 1
Header 8X2A | Header, 8-Pin, Dual roCN2 | HDR2X8_CEN | CMP-001-0325-01 | 1
B340A | DIODE SCHOTTKY 60D1,D3 | DO-214AC | CMP-001-0130-02 | 2
1N4448W-E3-18 | Diodes - General PurpoD2 | SOD 123 | CMP-001-0983-02 | 1
100 OHM 0603 1LN | 100 Ohms @ 100MHzFB1 | 0603-SMT | CMP-026-0038-02 | 1
SSR1028 6.8uH | INDUCTOR 6.8uH SML1 | SRU1028 | CMP-001-0686-01 | 1
SSR1210 100uH | INDUCTOR 100uH 2.2L2 | SRR1210 | CMP-001-0686-01 | 1
0603 LED | 0603 SMD LED | LED1 | SM-LED-0603 | CMP-001-0009-04 | 1
G | 0603 SMD LED | LED2 | SM-LED-0603 | 0603 LED | 1
MMBT2907A | PNP General Purpose AQ1,Q5 | SOT23 | CMP-012-0075-02 | 2
BSS123TA | MOSFET N-CH 100V 1Q2, Q4,Q6 | SOT23-3L | CMP-012-0021-01 | 3
MMBT3904 | NPN General Purpose AQ3 | SOT23 | MMBT3904 | 1
100 | RES 100 OHM 1% 1/1R1, R4,R23,R24 | RESC0603(1608)_N | CMP-007-0349-12 | 4
10K | RES 10K OHM 1/10W R2, R5,R6,R7, R8, R9RESC0603(1 608)_M | C MP-0 07-0359-12 | 15
0.33 | RES 0.33 OHM 1% 1/4R3 | RESC1206(3216)_N | CMP-007-0323-14 | 1
1.0K | RES 1K OHM 1% 1/10R12,R13, R15, R16, RRESC0603(1608)_M | CMP-007-0404-12 | 9
33K | RES 33K OHM 1/10W R18 | RESC0603(1608)_N | CMP-007-0480-12 | 1
100K | RES 100K OHM 1% 1/R21 | RESC0603(1608)_M | CMP-007-0353-12 | 1
TPS7A4515KTTR | TPS7A4515KTTR, lineaU 1 | TPS7A4515KTTR | TPS7A4515KTTR | 1
INA180A1 | U2 | SOT-23-5_MC | INA180A1 | 1
INA219 | Current Monitor IC | U3 | INA219 | INA219 | 1
OPA2320 | Dual Single Supply RaiU4,U9 | SOIC-8_NoPad | CMP-006-0027-01 | 2
LM334 | LM334, Current sourcU5 | LM334 | LM334 | 1
mcp9808 | U6 | 8MSOP | mcp9808 | 1
mcp4728 | MCP4728 | U7 | MCP4728 | mcp4728 | 1
ISL21010CF315Z | U8 | SOT23 | ISL21010CF315Z | 1

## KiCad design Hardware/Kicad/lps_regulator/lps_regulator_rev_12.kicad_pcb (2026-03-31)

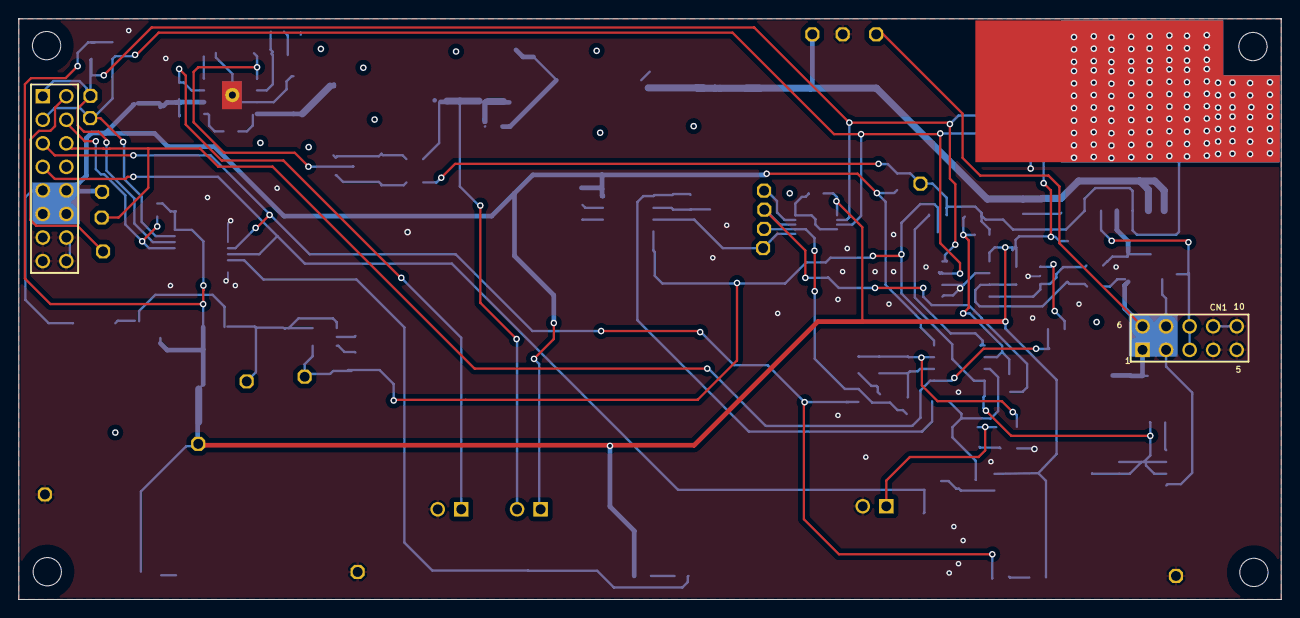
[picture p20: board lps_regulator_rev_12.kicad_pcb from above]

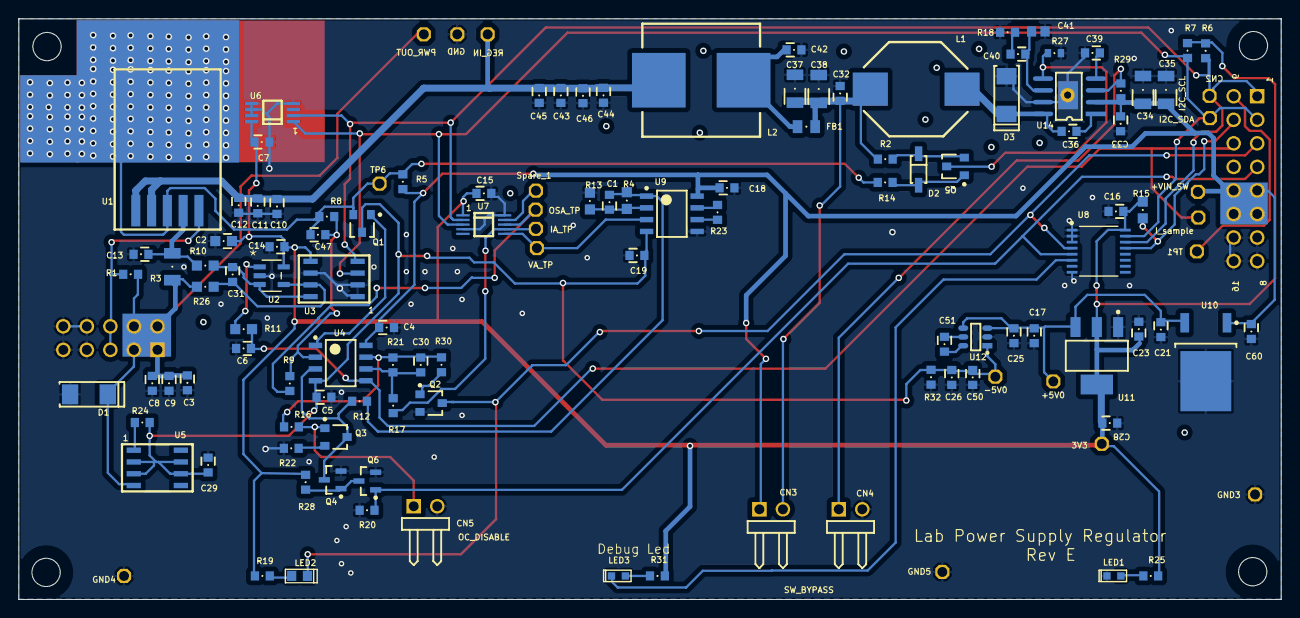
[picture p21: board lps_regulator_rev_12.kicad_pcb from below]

Board: 2 copper layers, 136.2 x 62.6 mm, 130 parts (109 on the bottom side), 55 nets.

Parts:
3V3: TestPoint_BLK; TestPoint-TH 42 mil
+5V0: TestPoint_BLK; TestPoint-TH 42 mil
+VIN_SW: TestPoint_BLK; TestPoint-TH 42 mil
-5V0: TestPoint_BLK; TestPoint-TH 42 mil
C1: 100pF; CAPC0603(1608)_N
C2: 0.1uF; CAPC0603(1608)_M
C3, C4, C5, C7, C12, C13, C14, C15, C16, C18, C19, C21, C23, C26, C29, C31, C32, C36, C42, C44, C47: 0.1uF; CAPC0603(1608)_N
C6, C8, C9, C10, C11, C17, C25, C28, C30, C43, C45, C50: 10uF; CAPC0603(1608)_N
C33, C39: 0.01uF; CAPC0603(1608)_N
C34, C35: 4.7uF; CAPC1206(3216)_N
C37, C38: 47UF; CAPC1206(3216)_N
C40: 150pF; CAPC0603(1608)_N
C41: 8.2nF; CAPC1608X87X35ML15T15
C46, C51, C60: 1uF; CAPC0603(1608)_N
CN1: Header 5X2A; HDR2X5_CEN
CN2: Header 8X2A; HDR2X8_CEN
CN3, CN4, CN5: Header 2H; HDR1X2H
D1, D3: B340A; DO-214AC
D2: 1N4448W-E3-18; SOD123
FB1: 300 Ohm @ 100MHz, 0805; RESC0805(2012)_N
GND, GND3, GND4, GND5: TestPoint_BLK; TestPoint-TH 42 mil
I2C_SCL, I2C_SDA: TestPoint_BLK; TestPoint-TH 42 mil
IA_TP: TestPoint_BLK; TestPoint-TH 42 mil
I_sample: TestPoint_BLK; TestPoint-TH 42 mil
L1: SSR1028 6.8uH; SRU1028
L2: SSR1210 100uH; SRR1210
LED1, LED3: 0603 LED; SM-LED-0603
LED2: G; SM-LED-0603
OSA_TP: TestPoint_BLK; TestPoint-TH 42 mil
PWR_OUT: TestPoint_BLK; TestPoint-TH 42 mil
Q1, Q5: MMBT2907A; SOT23
Q2, Q3: MMBT3904; SOT23
Q4, Q6: BSS123TA; SOT23-3L
R1, R23, R24: 100; RESC0603(1608)_N
R2, R5, R6, R7, R8, R9, R14, R20, R28, R29: 10K; RESC0603(1608)_N
R3: 0.33; RESC1206(3216)_N
R4, R13, R15: 10k; RESC0603(1608)_M
R10, R11, R26: 10K; RESC0603(1608)_M
R12, R16, R17, R19, R22, R25, R30, R31, R32: 1.0K; RESC0603(1608)_N
R18: 33K; RESC0603(1608)_N
R21: 100K; RESC0603(1608)_N
R27: 10K; RESC0603(1608)_L
REG_IN: TestPoint_BLK; TestPoint-TH 42 mil
Spare_1: TestPoint_BLK; TestPoint-TH 42 mil
TP1, TP6: TestPoint_BLK; TestPoint-TH 42 mil
U1: TPS7A4515KTTR
U2: INA180A1; SOT-23-5_MC
U3: INA219
U4, U9: OPA2320; SOIC-8_NoPad
U5: LM334
U6: mcp9808; 8MSOP
U7: mcp4728; MCP4728
U8: TCA9534APWR; TCA9534APWR-Footprint-1
U10: TO-252_N
U11: LD1117S33; DSO-G3
U12: LM2776; SOt-23-6
U14: TPS54331
VA_TP: TestPoint_BLK; TestPoint-TH 42 mil

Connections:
3V3: 3V3.1, C2.1, C7.1, C14.1, C15.1, C16.1, C23.1, C28.1, R6.1, R7.1, R15.2, R19.1, R25.1, R28.1, R31.1, U2.5, U3.5, U6.8, U7.1, U8.16, U11.2, U11.4
+5V0: +5V0.1, C17.1, C21.1, C25.1, U10.3, U11.3, U12.3, U12.4
+VIN_SW: +VIN_SW.1, C4.1, C18.1, C33.1, C34.1, C35.1, C60.1, CN2.5, CN2.6, CN2.13, CN2.14, CN3.1, R5.1, R29.1, U4.8, U9.8, U10.1, U14.2
-5V0: -5V0.1, C5.1, C19.2, C26.1, C29.2, C50.1, Q1.3, R24.2, R32.1, U4.4, U5.2, U5.3, U5.6, U5.7, U9.4, U12.1
/INT: CN2.10, R15.1, U8.13
/RST: CN2.9, TP1.1
Current_Limit: CN2.3, LED2.2, Q2.3, U8.4
Debug_LED: LED3.2, U8.6
GND: C2.2, C3.2, C4.2, C5.2, C6.2, C7.2, C8.2, C9.2, C10.2, C11.2, C12.2, C13.2, C14.2, C15.2, C16.2, C17.2, C18.2, C19.1, C21.2, C23.2, C25.2, C26.2, C28.2, C29.1, C32.2, C33.2, C34.2, C35.2, C37.2, C38.2, C39.2, C41.1, C42.2, C43.2, C44.2, C45.2, C46.2, C50.2, C60.2, CN1.4, CN1.5, CN1.9, CN1.10, CN2.7, CN2.8, CN2.15, CN2.16, CN4.2, CN5.2, D1.1, D3.1, GND.1, GND3.1, GND4.1, GND5.1, LED1.2, Q2.2, Q4.2, Q6.2, R13.1, R18.2, R20.2, R22.2, R27.2, R32.2, U2.2, U3.1, U3.2, U3.6, U6.4, U6.5, U6.6, U6.7, U7.4, U7.10, U8.1, U8.2, U8.3, U8.8, U9.5, U10.4, U11.1, U12.2, U14.7, U14.9
I2C_SCL: CN2.1, I2C_SCL.1, R6.2, U3.4, U6.2, U7.2, U8.14
I2C_SDA: CN2.2, I2C_SDA.1, R7.2, U3.3, U6.1, U7.3, U8.15
IA_TP: IA_TP.1, R17.1, U7.7
I_Sample: C6.1, CN2.11, I_sample.1, R11.2, U4.5
NetC1_1: C1.1, R4.1, R13.2, U9.2
NetC17_1: C51.1, U12.5
NetC17_2: C51.2, U12.6
NetC30_1: C30.1, R16.1, R21.2, R30.2, U4.7
NetC30_2: C30.2, R17.2, R21.1, U4.6
NetC31_1: C31.1, R10.1, U2.3, U3.8
NetC31_2: C31.2, R26.1, U2.4, U3.7
NetC32_1: C32.1, C37.1, C38.1, CN3.2, FB1.1, L1.2, R2.1
NetC36_1: C36.1, U14.1
NetC36_2: C36.2, D3.2, L1.1, U14.8
NetC39_1: C39.1, U14.4
NetC40_1: C40.1, C41.2, U14.6
NetC40_2: C40.2, R18.1
NetC42_1: C42.1, FB1.2, L2.1
NetC47_1: C47.1, Q1.2, R5.2, R8.1, R14.2, TP6.1, U1.3, U1.6
NetC47_2: C47.2, R8.2, R9.1, U4.2
NetCN1_3: CN1.3, CN1.8, R1.2, U1.5
NetCN4_1: CN4.1, R29.2, U14.3
NetCN5_1: CN5.1, Q3.1, R16.2
NetD2_1: D2.1, Q5.1, R14.1
NetD2_2: D2.2, Q5.2, R2.2
NetLED1_1: LED1.1, R25.2
NetLED2_1: LED2.1, R19.2
NetLED3_1: LED3.1, R31.2
NetQ1_1: Q1.1, U4.1
NetQ2_1: Q2.1, R30.1
NetQ3_2: Q3.2, R22.1
NetQ3_3: Q3.3, Q4.3, R12.2, U4.3
NetQ4_1: Q4.1, Q6.3, R28.2
NetQ5_3: Q5.3, R27.1, U14.5
NetR11_1: R11.1, U2.1
NetR23_1: R23.1, U9.6
NetR23_2: R23.2, U9.7
NetR24_1: R24.1, U5.1
NetSpare_1_1: Spare_1.1, U7.9
OUTPUT_ENB: CN2.4, Q6.1, R20.1, U8.5
Pwr_Out: C3.1, C8.1, C9.1, CN1.1, CN1.2, CN1.6, CN1.7, D1.2, PWR_OUT.1, R1.1, R3.2, R26.2, U5.4
Pwr_Out_Sample: C13.1, R3.1, R10.2, U1.4
REG_VIN: C10.1, C11.1, C12.1, C43.1, C44.1, C45.1, C46.1, L2.2, REG_IN.1, U1.1, U1.2
VA_TP: U7.6, U9.3, VA_TP.1
VA_TP_GAIN: C1.2, R4.2, R12.1, U9.1
V_offset_adj: OSA_TP.1, R9.2, U7.8

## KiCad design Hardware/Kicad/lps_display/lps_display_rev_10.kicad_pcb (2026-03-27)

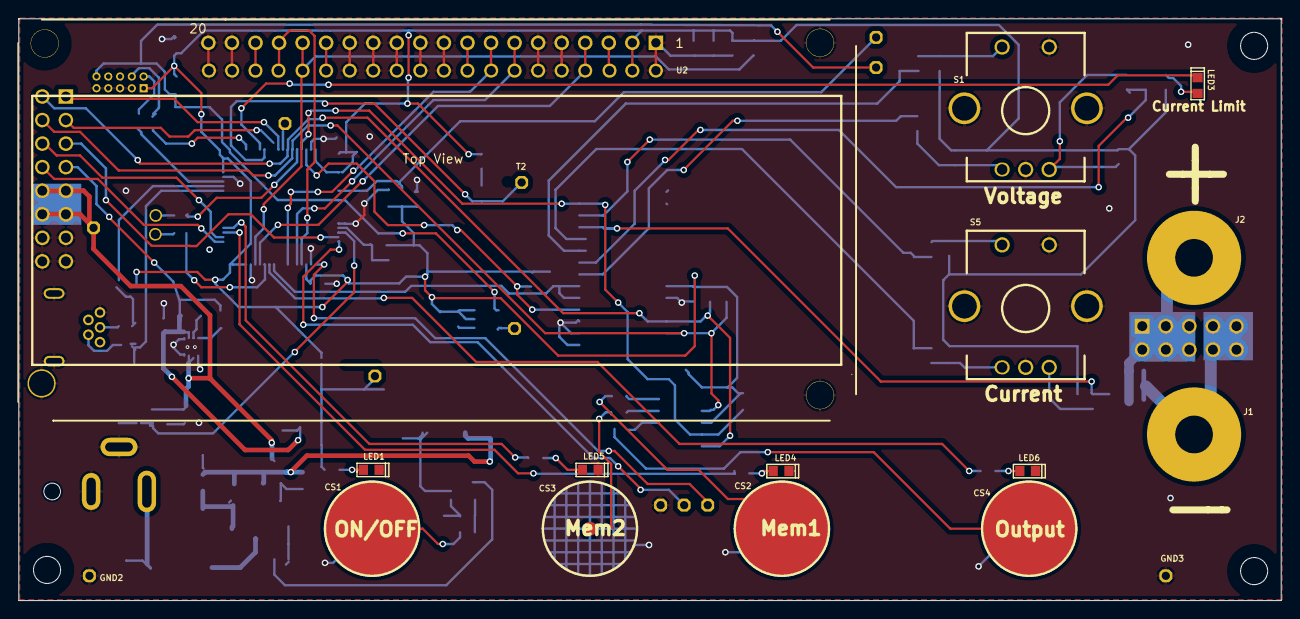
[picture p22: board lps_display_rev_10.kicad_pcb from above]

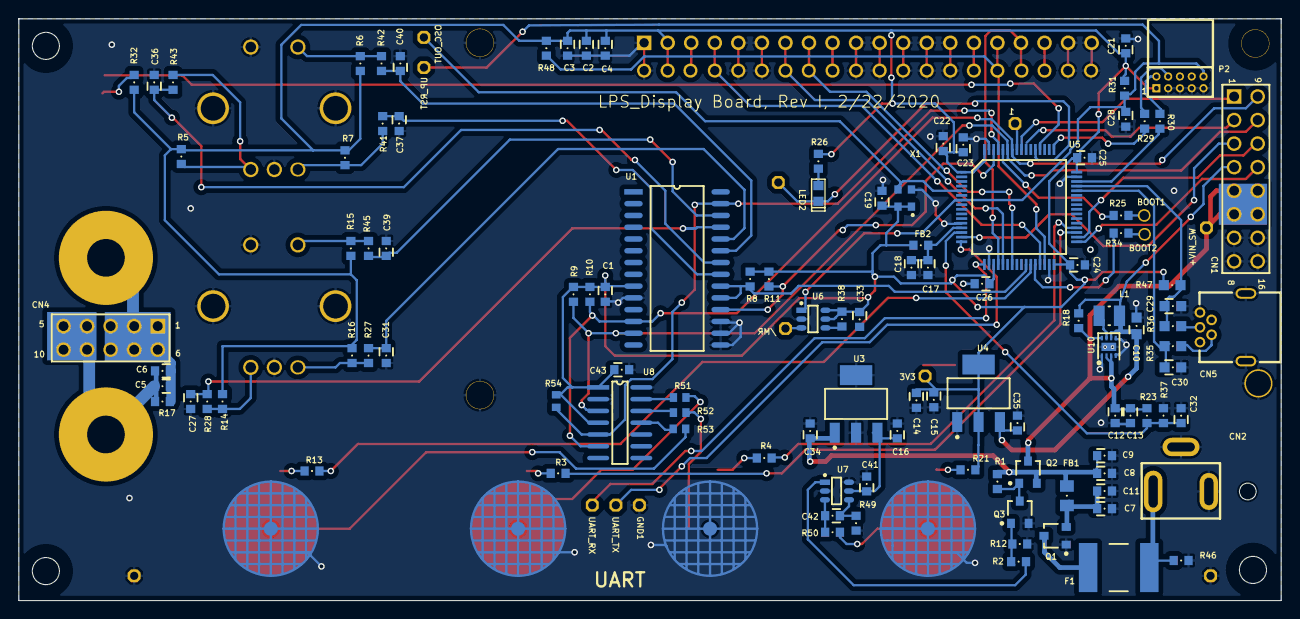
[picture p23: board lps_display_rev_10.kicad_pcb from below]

Board: 2 copper layers, 136.1 x 62.7 mm, 137 parts (112 on the bottom side), 84 nets.

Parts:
1, 3V3: TestPoint-TH 35 mil
+VIN_SW: TestPoint-TH 35 mil
/MR: TestPoint-TH 35 mil
BOOT1, BOOT2: TP; TestPoint-TH 40 mil
C1, C4, C6, C8, C11, C13, C15, C18, C19, C21, C23, C24, C25, C26, C27, C31, C32, C33, C34, C35, C36, C37, C39, C40, C41, C42, C43: 0.1uF 0603 50V; CAPC0603(1608)_N
C2, C3, C5, C7, C9, C12, C14, C16, C17, C22: 10uF; CAPC0603(1608)_N
C10: 22uF; CAPC0603(1608)_M
C28: 1uF; CAPC0603(1608)_N
C29, C30: 33pF; CAPC0603(1608)_M
CN1: Header 8X2A; HDR2X8_CEN
CN2: PJ-050AH
CN4: Header 5X2A; HDR2X5_CEN
CN5: Mini-USB RA Type B; USB-MINI-B - 2A
CS1, CS2, CS3, CS4: Cap_Sense_Pad; CAP_TOUCH_ROUND
F1: 2920L500/16MR; 2920 Fuse
FB1: 300 Ohm @ 100MHz, 0806; RESC0805(2012)_M
FB2: BLM18RK601SN1D; RESC0603(1608)_N
GND1, GND2, GND3: TestPoint-TH 35 mil
J1, J2: banana_jack1; Banana_jack1
L1: 2.2uH; INDC2520X10N
LED1, LED2, LED3, LED4, LED5, LED6: G; SM-LED-0603
OSC_OUT: TestPoint-TH 35 mil
P2: jtag_debug
Q1, Q2: DMP3099L-7; SOT23
Q3: MMBT3904; SOT23
R1, R2, R5, R6, R7, R8, R9, R10, R11, R12, R14, R15, R16, R17, R21, R27, R28, R38, R41, R42, R43, R45, R48: 4.7K; RESC0603(1608)_N
R3, R4, R13, R23, R26, R32, R37, R46, R49, R50: 1.0K; RESC0603(1608)_N
R18, R25, R34: 100K; RESC0603(1608)_N
R29, R30: 100; RESC0603(1608)_N
R31: 10K 1%; RESC0603(1608)_N
R35, R36: 22; RESC0603(1608)_M
R47: 1.54K; RESC0603(1608)_M
R51, R52, R53, R54: 5.1K; RESC1608X55X30NL15T15
S1, S5: rotary encoder
T2: TestPoint-TH 35 mil
U1: MCP23017; SOIC28
U2: OLED Display; oled_graphic_256X64
U3: TPS7B6933QDCYRQ1; SOT-223
U4: 3.3V; DSO-G3
U5: STM32F103RCT6; LQFP64
U6: TPS3808G33; SOt-23-6
U7: AT42QT1012; SOt-23-6
U8: AT42QT1070; SOP14
U10: TPS62173DSGT; WSON(8) 2mm x 2mm
UART_RX: TestPoint-TH 35 mil
UART_TX: TestPoint-TH 35 mil
UP_RST: TestPoint-TH 35 mil
X1: 8.0000MHZ; ECS-TXO-2520-33-160-AN-TR-Footprint-1

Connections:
3V3: 3V3.1, C1.1, C2.1, C3.1, C4.1, C14.1, C15.1, C19.1, C21.1, C22.1, C23.1, C24.1, C25.1, C26.1, C33.1, C43.1, FB2.1, P2.1, R5.2, R6.2, R7.2, R8.2, R9.2, R10.2, R11.2, R14.2, R15.2, R16.2, R21.2, R26.2, R31.1, R32.2, R38.2, R47.1, R48.2, R54.2, U1.9, U2.2, U4.2, U4.4, U5.1, U5.19, U5.32, U5.48, U5.64, U6.5, U6.6, U8.1, U8.4, X1.1, X1.4
5V0: C10.1, C35.1, CN1.4, L1.2, R18.1, U4.3, U10.6
8MH_XTAL_IN: OSC_OUT.1, U5.5, X1.3
+VIN: C8.1, C9.1, C34.1, FB1.2, Q2.2, R1.2, U3.1
+VIN_SW: +VIN_SW.1, C12.1, C13.1, CN1.5, CN1.6, CN1.13, CN1.14, Q2.3, R23.2, U10.2, U10.3
/CAP_T_INT: R54.1, U1.27, U5.61, U8.5
/INT: R8.1, U1.19, U1.20, U5.26
/RST_MCP23017: R11.1, U1.18, U5.62
/RST_OLED: R48.1, U2.16, U5.30
Current_Limit: CN1.11, U5.34
D/C_OLED: U2.4, U5.29
DEBUG_LED: LED2.2, T2.1, U5.53
GND: C1.2, C2.2, C3.2, C4.2, C7.2, C8.2, C9.2, C10.2, C11.2, C12.2, C13.2, C14.2, C15.2, C16.2, C17.2, C18.2, C19.2, C21.2, C22.2, C23.2, C24.2, C25.2, C26.2, C27.2, C28.2, C29.2, C30.2, C31.2, C32.2, C33.2, C34.2, C35.2, C36.2, C37.2, C39.2, C40.2, C41.2, C43.2, CN1.7, CN1.8, CN1.15, CN1.16, CN2.2, CN2.3, CN5.0, CN5.5, CS1.2, CS2.2, CS3.2, CS4.2, GND1.1, GND2.1, GND3.1, LED1.2, LED4.2, LED5.2, LED6.2, P2.3, P2.5, P2.7, P2.9, Q1.1, Q3.2, R12.2, R37.1, R46.1, R49.1, S1.2, S1.4, S1.5, S1.7, S5.2, S5.4, S5.5, S5.7, U1.10, U1.15, U1.16, U1.17, U2.1, U2.5, U2.6, U2.10, U2.11, U2.12, U2.13, U2.14, U2.19, U2.20, U3.2, U3.4, U4.1, U5.12, U5.18, U5.31, U5.47, U5.63, U6.2, U7.2, U7.6, U8.2, U8.14, U10.1, U10.4, U10.5, U10.9, X1.2
I2C_SCL: CN1.9, R10.1, U1.12, U5.58, U8.6
I2C_SDA: CN1.10, R9.1, U1.13, U5.59, U8.3
I_ENC_A: C31.1, R27.2, U1.24
I_ENC_B: C27.1, R28.2, U1.25
I_ENC_SW: C39.1, R45.1, U1.26
I_Sample: CN1.3, U5.15
MEM1_LED: R3.1, U5.35
MEM2_LED: R4.1, U5.36
NRST: C28.1, P2.10, R31.2, U5.7, U6.1, UP_RST.1
Net1_1: 1.1, U5.57
Net/MR_1: /MR.1, U6.3
NetBOOT1_1: BOOT1.1, R25.1
NetBOOT2_1: BOOT2.1, R34.2
NetC5_1: C5.1, C6.1, CN4.1, CN4.2, CN4.3, CN4.6, CN4.7, CN4.8, J2.1, R17.2
NetC5_2: C5.2, C6.2, CN4.4, CN4.5, CN4.9, CN4.10, J1.1, R17.1
NetC7_1: C7.1, C11.1, FB1.1, Q1.2
NetC16_1: C16.1, C41.1, U3.3, U7.5
NetC17_1: C17.1, C18.1, FB2.2, U5.13
NetC42_1: C42.1, R49.2, U7.4
NetC42_2: C42.2, R50.2, U7.3
NetCN2_1: CN2.1, F1.1, R46.2
NetCN5_2: CN5.2, R35.1
NetCN5_3: CN5.3, R36.1
NetCS1_1: CS1.1, R50.1
NetCS2_1: CS2.1, R51.2
NetCS3_1: CS3.1, R52.2
NetCS4_1: CS4.1, R53.2
NetF1_2: F1.2, Q1.3
NetL1_1: L1.1, U10.7
NetLED1_1: LED1.1, R21.1
NetLED2_1: LED2.1, R26.1
NetLED3_1: LED3.1, R32.1
NetLED4_1: LED4.1, R3.2
NetLED5_1: LED5.1, R4.2
NetLED6_1: LED6.1, R13.2
NetP2_2: P2.2, R30.1
NetP2_4: P2.4, R29.1
NetQ2_1: Q2.1, Q3.3, R1.1
NetQ3_1: Q3.1, R2.1, R12.1
NetR2_2: R2.2, U7.1
NetR5_1: R5.1, R43.1, S1.3
NetR6_1: R6.1, R42.2, S1.6
NetR7_1: R7.1, R41.1, S1.1
NetR14_1: R14.1, R28.1, S5.3
NetR15_1: R15.1, R45.2, S5.6
NetR16_1: R16.1, R27.1, S5.1
NetR18_2: R18.2, U10.8
NetR25_2: R25.2, U5.60
NetR34_1: R34.1, U5.28
NetR38_1: R38.1, U6.4
NetR51_1: R51.1, U8.13
NetR52_1: R52.1, U8.12
NetR53_1: R53.1, U8.11
OC_LED: LED3.2, U5.52
OUTPUT_ENB: CN1.12, U5.33
OUTPUT_LED: R13.1, U5.27
SPI_MOSI_1: U2.8, U5.23
SPI_NSS_1: U2.17, U5.20
SPI_SCK_1: U2.7, U5.21
Spare1: CN1.2, U5.55
Spare2: CN1.1, U5.56
TCK/SWDCLK: R29.2, U5.49
TMS/SWDIO: R30.2, U5.46
UART_RX_2: U5.17, UART_RX.1
UART_TX_2: U5.16, UART_TX.1
USBDM: C30.1, R35.2, U5.44
USBDP: C29.1, R36.2, R47.2, U5.45
VIN_CHK: C32.1, R23.1, R37.2, U5.14
V_ENC_A: C37.1, R41.2, U1.21
V_ENC_B: C36.1, R43.2, U1.22
V_ENC_SW: C40.1, R42.1, U1.23

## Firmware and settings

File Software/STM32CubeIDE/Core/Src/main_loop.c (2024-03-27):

/*
 * main_loop.c, Jerry OKeefe, 3/6/24
 */

#include "main.h"
#include <string.h>
#include <stdio.h>
//#include <stdlib.h>
#include <stdbool.h>
//#include <ctype.h>
//#include <stdint.h>

#include "main_loop.h"
#include "led_drv.h"
#include "mcp9808.h"
#include "mcp23017.h"
#include "at42qt1070.h"
#include "ina219_drv.h"
#include "ugui.h"
#include "oled_drv.h"
#include "i2c_scan.h"

// indent -gnu -br -cli2 -lp -nut -l100 main_loop.c

parameters_t param = {
  0.0,                          // v_out;
  0.0,                          // i_out;
  0.0,                          // v_set;
  0.0,                          // i_set;
  0.0,                          // p_out;
  0.0,                          // v_in;
  0.0,                          // heatsink_temp;
  0.0,                          // cpu_temp;  
  0.0,                          // mem1_v_set;
  0.0,                          // mem2_v_set;

  0,                            // mode;
  0,                            // out_on;
  0,                            // lock;  
  0,                            // ticks;  // param.ticks
};

enum LPS_MODE {
  CV,
  CC
};

/// @brief 
typedef struct _oled_values
{
  float volts;
  float amps;
  int bar_len;
  float v_set;
  float i_set;
  int lps_mode;
  float temp_c;
  float top_voltage_limit;
  float Vin;
  int output_state;
  int ticks;
} oled_values_t;

oled_values_t oled2;

void oled_lps (void);
void cap_touch_update (void);
void rotaryVoltageProcess (int encoder_inputs);
void rotaryCurrentProcess (int encoder_inputs);
void encoders_check_status(void);
void oled_update (oled_values_t * p);
int lps_loop (void);

void
oled_default_load (void)
{
  oled2.volts = 3.3;
  oled2.amps = 0.41;
  oled2.v_set = 5.0;
  oled2.i_set = 1.5;
  oled2.bar_len = 125;
//  oled2.last_voltage_preset = 5.0;
  oled2.lps_mode = CV;
  oled2.temp_c = 27.4;
  oled2.top_voltage_limit = 8.0;
  oled2.Vin = 12.2;
  // oled2.Vtop = 9.1;
  oled2.output_state = 0;
  oled2.ticks = param.ticks;
}

extern ADC_HandleTypeDef hadc1;

static volatile bool show_rx = true;    // false;
float mcp9808_float_temp = 0.0;
char mcp9808_str[20] = "26.3";  // "x.x";
char Vin_str[30] = "0.0";
char Vtop_str[30] = "12.0";
#define REGULATOR_DROP (3.0)
float top_voltage_limit = 15.00;        // This should be calculated from input voltage

float millivolts = 0.0;
float milliamps = 0.0;

#define MEM1_VOLTAGE_PRESET 3.3 // was 3.3
#define MEM1_CURRENT_PRESET 0.5 // 1.2

#define MEM2_VOLTAGE_PRESET 5.0
#define MEM2_CURRENT_PRESET 0.5 // 1.5

float mem1_voltage_preset = MEM1_VOLTAGE_PRESET;        // normally 3.3 volts
float mem1_current_preset = MEM1_CURRENT_PRESET;        // normally 3.3 volts

float mem2_voltage_preset = MEM2_VOLTAGE_PRESET;
float mem2_current_preset = MEM2_CURRENT_PRESET;

float last_voltage_preset = 0.0;
//volatile TickType_t mem1_press_time = 0;        // for xTaskGetTickCount ();
//volatile TickType_t mem2_press_time = 0;

uint32_t output_state = 0;
uint32_t mem1_state = 0;
uint32_t mem2_state = 0;

volatile int mem1_press_time = 0;       // for xTaskGetTickCount ();
volatile int mem2_press_time = 0;

typedef struct _cursor
{
  int cursor_on;
  int position;
  int multi;
} cursor_t;

cursor_t cursor_voltage = {
  0,                            // cursor cursor_on
  0,                            // cursor position
  1                             // cursor multi
};

cursor_t cursor_current = {
  0,                            // cursor cursor_on
  0,                            // cursor position
  1                             // cursor multi
};

int voltage_cursor_on = 0;
int voltage_position = 0;
int voltage_multi = 1;

int current_cursor_on = 0;
int current_position = 0;
int current_multi = 1;

mov_avg_t volts_mov_avg;
mov_avg_t current_mov_avg;

int show_status_flag = 0;
int log_interval = 10;
int debug_flag = 1;

int program_bytes = 0;
static const char pOFF[] = { "OFF" };

const char *mode_str = pOFF;

uint8_t V_RotaryCurrentState = 0x00;
uint8_t V_RotaryTransition = 0;
int V_RotaryPosition = 0;
int V_RotaryPosition_last = 0;
uint8_t I_RotaryCurrentState = 0x00;
uint8_t I_RotaryTransition = 0;
int I_RotaryPosition = 0;
int I_RotaryPosition_last = 0;

int flash_stack_size = 0;
int console_stack_size = 0;
int bounce_stack_size = 0;
int oled_stack_size = 0;

  /* USER CODE BEGIN 1 */
HAL_StatusTypeDef ret;
uint8_t buf[50];
int16_t val;
float temp_c;
int i = 0;
int err = 0;
int16_t gpio_reg = 0;

void
output_enb (int enb)            // to enable the output
{
  if (enb) {
    led_on (OUTPUT_LED);
    param.out_on = 1;
    HAL_GPIO_WritePin (GPIOB, GPIO_PIN_12, 1);
  }
  else {
    led_off (OUTPUT_LED);
    param.out_on = 0;
    HAL_GPIO_WritePin (GPIOB, GPIO_PIN_12, 0);
  }
}

#define FALLING_EDGE 0
#define RISING_EDGE  1
void
output_button_CB (int edge_dir)
{
  printf ("Output Button edge %d\r\n", edge_dir);
  if (edge_dir == FALLING_EDGE) {
    // toggle output state
    output_state = !output_state;
  }

  if (output_state & 1) {
    voltage_wrt (param.v_set);
    led_on (OUTPUT_LED);
    output_enb (1);
  }
  else {
//    voltage_zero_wrt (); // This is not needed. OUTPUT_ENB will disable output
    output_enb (0);
    led_off (OUTPUT_LED);
  }
}

void
mem1_button_CB (void)
{
  param.v_set = mem1_voltage_preset;
  last_voltage_preset = mem1_voltage_preset;
  param.i_set = mem1_current_preset;
  // don't need to check output state because output control block output
  voltage_wrt (param.v_set);
  current_wrt (param.i_set);

  led_on (MEM1_LED);
  led_off (MEM2_LED);
  init_cursors ();              // init encoder change resolution

  if (debug_flag) {
    printf ("Mem1 Button press\r\n");
  }
  return;
}

void
remote_voltage_preset (float preset_voltage)
{
  led_off (MEM1_LED);
  led_off (MEM2_LED);
  param.v_set = preset_voltage;
  last_voltage_preset = param.v_set;
  voltage_wrt (param.v_set);
}

void
remote_current_preset (float preset_current)
{
  led_off (MEM1_LED);
  led_off (MEM2_LED);
  param.i_set = preset_current;
  current_wrt (param.i_set);
}

void
mem2_button_CB (void)
{
  param.v_set = mem2_voltage_preset;
  last_voltage_preset = mem2_voltage_preset;
  param.i_set = mem2_current_preset;
  // don't need to check output state because output control block output
  voltage_wrt (param.v_set);
  current_wrt (param.i_set);

  led_on (MEM2_LED);
  led_off (MEM1_LED);
  init_cursors ();        // init encoder change resolution

  if (debug_flag) {
    printf ("Mem2 Button press\r\n");
  }
  return;
}

int
diag_system (void)
{
  float temp_c = 0;
  int i2c_device = 0;

  printf ("\r\n\r\n\r\nRun Diagnostic Tests\r\n");

  i2c_device = i2c_scan ();
  printf ("i2c devices found: %d\r\n", i2c_device);

  // on board I2C items
  printf ("mcp23017_access_test: ");
  mcp23017_access_test ();
  printf ("Passed\r\n");

  printf ("at42qt1070_access_test: ");
  at42qt1070_key_status ();
  printf ("Passed\r\n");

  // remote baord I2C items
  printf ("mcp9808_access_test: ");

  temp_c = mcp9808_read ();     // read and convert to Deg C
  printf ("Passed %3.2f C\r\n", temp_c);

  printf ("ina219_access_test: ");
  ina219_access_test ();
  printf ("Passed\r\n");

  printf ("mcp4728_access_test: ");
  mcp4728_access_test();
  printf ("Passed\r\n");

  return 0;
}

void
init_cursors (void)
{
  cursor_voltage.cursor_on = 0;
  cursor_voltage.position = 0;
  cursor_voltage.multi = 0;

  cursor_current.cursor_on = 0;
  cursor_current.position = 0;
  cursor_current.multi = 0;

  voltage_cursor_on = 0;
  voltage_position = 2;
  voltage_multi = 50;

  current_cursor_on = 0;
  current_position = 2;
  current_multi = 50;
}

/*********************************************************************
 * Read ADC Channel
 *********************************************************************/

int
adc_read (int ch)
{
  int adc_val = 0;
  HAL_ADC_Start (&hadc1);       // start the adc 

  HAL_ADC_PollForConversion (&hadc1, 100);      // poll for conversion 

  adc_val = HAL_ADC_GetValue (&hadc1);  // get the adc value 

  HAL_ADC_Stop (&hadc1);        // stop adc 
  return adc_val;
}

float
read_Vin (void)
{
  param.v_in = ((float) adc_read (ADC_CHANNEL_0) / 104.5);      // Need 1% resistors here!
  return param.v_in;
}

void
read_environment(void)
{
  int temp100, vref;
  int adc0;

  temp100 = degrees_C100 ();
  vref = adc_read (ADC_CHANNEL_VREFINT) * 330 / 4095;   // 
  adc0 = (adc_read (ADC_CHANNEL_0) * 330 / 4095) * 11.875; // VIN_CHK
//  adc1 = read_adc (1) * 330 / 4095;
  printf ("Temperature %d.%02d C, Vref %d.%02d Volts, ch0 %d.%02d V\r\n",
          temp100 / 100, temp100 % 100, vref / 100, vref % 100, adc0 / 100, adc0 % 100);

  printf ("Vin: %3.3fV, Vtop: %sV\r\n", read_Vin(), Vtop_str);
}

int
degrees_C100 (void)
{
  int vtemp;
  static const int v25 = 1365;  // see https://github.com/ve3wwg/stm32f103c8t6/issues/11

  vtemp = adc_read (ADC_CHANNEL_TEMPSENSOR);
//  vtemp = (int)adc_read(ADC_CHANNEL_TEMPSENSOR) * 3300 / 4095;
  return (v25 - vtemp) * 1000 / 45 + 2500;      // temp = (1.43 - Vtemp) / 4.5 + 25.00
}

int
lps_setup (void)
{

  printf ("=====================\r\n");
  printf ("=====================\r\n");
  printf ("%s Built on: %s @ %s\r\n", __FILE__, __DATE__, __TIME__);
  printf ("%d, %s %s(%d)\r\n", i++, __FILE__, __func__, __LINE__);

  HAL_Delay (100);

//  i2c_scan ();
  diag_system ();

  oled_init_real ();
  oled_init_ssd1322 ();
  splash_scr ();

  mcp23017_reset ();
  mcp23017_init (0xFFFF);       // 0xffff;  // default io_dir as inputs
  // Init the hardware
  led_all_on ();
  ina219_reset ();
  mcp4728_init ();
  ina219_init ();

  output_enb (0);   // Disable output
  param.v_set = 0.0;
  param.i_set = 1.5;

  voltage_wrt (param.v_set);
  current_wrt (param.i_set);
  printf ("v_set: %3.2fV, iset: %3.2fA\r\n", param.v_set, param.i_set);

  at42qt1070_show_status ();

  read_environment();

  return 0;
}


 // https://electronics.stackexchange.com/questions/99915/stm32-rotary-encoder-with-hardware-interrupts
static const int8_t enc_states[] = { 0, -1, 1, 0, 1, 0, 0, -1, -1, 0, 0, 1, 0, 1, -1, 0 };

int
lps_loop (void)
{
  int line_len = 0;
  float amps = 0.0;
  param.v_set = 3.3;
  uint16_t mcp23017_io_dir = 0;

  init_cursors ();
  led_all_on ();

//  oled_display_off();
  oled_init_real ();     // clears pix map and init th ugui driver.
  oled_init_ssd1322 ();

  UG_SetBackcolor (C_WHITE);
  UG_SetForecolor (C_BLACK);

  splash_scr ();

  led_all_off ();

// Clear at42qt1070 "Change" interrupt line
//  gpio_set_mode (GPIOB, GPIO_MODE_INPUT, GPIO_CNF_INPUT_FLOAT, GPIO8); 

  at42qt1070_init ();           // 100millisec delay
  at42qt1070_det_status ();     // clear any stale status 
  at42qt1070_key_status ();     // clear any stale status

  // Setup MCP23017 Outputs
  mcp23017_reset ();
  mcp23017_io_dir = 0xffff;     // default io_dir as inputs
  mcp23017_init (mcp23017_io_dir);

  // Setup interrupt registers
  mcp23017_write16 (GPINTEN_REG, 0x007f);
  mcp23017_write16 (DEFVAL_REG, 0x0000);
  mcp23017_write16 (INTCON_REG, 0x0000);        // interrupt on rising or falling logic

//  oled_init_all ();
  int start_time = HAL_GetTick ();
  int last_tick = start_time;
  int new_tick = start_time;
//  int sub_64_tick = 0;
  int last_display_update_tick = start_time;
//  int last_oled_update_tick = start_time;

  param.v_set = 0.0;
  param.i_set = 1.5;
  voltage_wrt (param.v_set);
  current_wrt (param.i_set);

  oled_default_load ();

  for (;;) {
    new_tick = HAL_GetTick ();
//    printf("enc %d\r\n",new_tick);
    if (last_tick != new_tick) {
      last_tick = new_tick;
      led_toggle (DEBUG_LED);   // (OUTPUT_LED);
      // Check mcp23017 Int line
//      if ((sub_64_tick & 0x07) == 0){
//      cap_touch_update ();      // Should use touch GPIO pin 
//      }

      // Any change on the voltage/Current encoders
      encoders_check_status();

      if (new_tick > (last_display_update_tick + 1000)) {
        last_display_update_tick = new_tick;
//      printf ("oled %d\r\n", new_tick);
        encoders_check_status();

        oled2.volts = voltage_read ();
        oled2.amps = current_read ();
        oled2.v_set = param.v_set;
        oled2.i_set = param.i_set;
        oled2.bar_len = line_len = (int) ((amps * 256.0) / param.i_set);
        oled2.lps_mode = CV;
        oled2.temp_c = mcp9808_read ();
        oled2.top_voltage_limit = top_voltage_limit;
        oled2.Vin = read_Vin ();

        encoders_check_status();

//      oled2.Vtop = 9.1;
//      oled2.ticks = param.ticks & 0xff;
        oled2.output_state = param.out_on;      // output_state;
        oled2.ticks = HAL_GetTick () % 100;     // TaskGetTickCount () / 1000);
        oled_update (&oled2);  // build screen picture

        encoders_check_status();

        oled_update_ssd1322 (); // Send to OLED
      }
    }
  }
}

void
cap_touch_update (void)
{
  uint8_t key_status = 0;
//  static volatile int press_time = 0;
//  static volatile int release_time = 0;
//  static volatile int press_time_diff = 0;
//  static volatile int press_long = 0;

  if (HAL_GPIO_ReadPin (GPIOB, GPIO_PIN_8) == 0) {

    at42qt1070_det_status ();
    key_status = at42qt1070_key_status () & 0x07;
//    switch (key_value) {
    switch (key_status) {
      case 1:
        mem1_button_CB ();
        break;
      case 2:
        mem2_button_CB ();
        break;
      case 4:
        output_button_CB (0);
        break;
    }
  }
}

void encoders_check_status(void) 
{
  uint16_t mcp23017_inputs = 0;

  if (HAL_GPIO_ReadPin (GPIOB, GPIO_PIN_0) == 0) {
       mcp23017_inputs = mcp23017_read16 (GPIO_REG);
      rotaryVoltageProcess (mcp23017_inputs & 0x07);  // Only these encoders bits

      rotaryCurrentProcess ((mcp23017_inputs >> 3) & 0x7);    // Only these encoders bits
  }
  cap_touch_update ();      // Should use touch GPIO pin 
}

void
rotaryVoltageProcess (int encoder_inputs)
{
  float millivolts = 0.0;
  static int last_encoder_inputs;

  encoder_inputs &= 0x7;
  /* Check for V encoder bit change */
  if (last_encoder_inputs == encoder_inputs) {
    // Just return if no change
    return;
  }
  V_RotaryCurrentState = encoder_inputs & 3;
  V_RotaryTransition = (V_RotaryTransition << 2) | V_RotaryCurrentState;
  V_RotaryPosition = V_RotaryPosition + enc_states[V_RotaryTransition & 0x0F];
  if (V_RotaryPosition != V_RotaryPosition_last) {
    printf ("V encoder: %d, %d\r\n", encoder_inputs & 3, V_RotaryPosition);
    V_RotaryPosition_last = V_RotaryPosition;
    millivolts = (float) ((enc_states[V_RotaryTransition & 0x0F] * voltage_multi) * 0.001);
    param.v_set -= millivolts;  // why neg
    printf ("V encoder: %d, %d, %2.2f %3.2f\r\n", encoder_inputs & 3, V_RotaryPosition, millivolts,
            param.v_set);
    // Check for legal voltage range
    if (param.v_set > top_voltage_limit) {
      param.v_set = top_voltage_limit;
    }
    if (param.v_set < 0.0) {
      param.v_set = 0.0;
    }
    last_voltage_preset = param.v_set; // what does last_voltage_preset do?
    voltage_wrt (param.v_set);
  }

  // Get the SW buttons edge state
  if ((last_encoder_inputs & 1 << 2) != (encoder_inputs & 1 << 2)) {
    if ((encoder_inputs & 1 << 2) == 0) {
//          voltage_button (sw_state);
      printf ("V encoder button pressed!\r\n");
    }
  }
  last_encoder_inputs = encoder_inputs;
}

void
rotaryCurrentProcess (int encoder_inputs)
{
  float milliamps = 0.0;
  static int last_encoder_inputs;

  encoder_inputs = encoder_inputs & 0x7;;
  /* Check for I encoders bit change */
  if (last_encoder_inputs == (encoder_inputs)) {
    return; // Just return if no change
  }

  // Process current encoder changes
  I_RotaryCurrentState = encoder_inputs & 3;
  I_RotaryTransition = (I_RotaryTransition << 2) | I_RotaryCurrentState;
  I_RotaryPosition = I_RotaryPosition + enc_states[I_RotaryTransition & 0x0F];
  if (I_RotaryPosition != I_RotaryPosition_last) {
    printf ("I encoder: %d, %d\r\n", (encoder_inputs >> 3) & 3, I_RotaryPosition);
    I_RotaryPosition_last = I_RotaryPosition;
    printf ("I encoder: %d, %d, %2.2f %3.2f\r\n", (encoder_inputs >> 3) & 3,
            I_RotaryPosition, milliamps, param.i_set);
    milliamps = (float) ((enc_states[I_RotaryTransition & 0x0F] * current_multi) * 0.001);
    param.i_set -= milliamps;
    if (param.i_set > 1.5) {
      param.i_set = 1.5;
    }
    if (param.i_set < 0.0) {
      param.i_set = 0.0;
    }
    led_off (MEM1_LED);
    led_off (MEM2_LED);
    current_wrt (param.i_set);
  }

  // Get the SW buttons edge state
  if ((last_encoder_inputs & 1 << 2) != (encoder_inputs & 1 << 2)) {
    if ((encoder_inputs & 1 << 2) == 0) {
//          current_button (sw_state);
      printf ("I encoder button pressed!\r\n");
    }
  }

  last_encoder_inputs = encoder_inputs;;
}

void
oled_update (oled_values_t * p)
{
  char buf[60];
  char str[20];

  clear_pixmap ();        // Without this we get overlap chars
  UG_SetBackcolor (C_WHITE);
  UG_SetForecolor (C_BLACK);
  UG_FontSelect (&FONT_12X16);

  snprintf (buf, sizeof buf, "Out: %3.3fV, %3.3fA", p->volts, p->amps);
  UG_PutString (0, 0, buf);

  // Draw analog line matching percentage of load current limit.
  for (i = 0; i < 8; i++) {     // draw four lines
    // Full scale set to current limit
    UG_DrawLine (0, BAR_ROW + i, p->bar_len, BAR_ROW + i, C_BLACK);
  }
  UG_FontSelect (&FONT_8X12);   // Change to lower font

  snprintf (buf, sizeof buf, "Sets: %3.3fV, %3.3fA", p->v_set, p->i_set);
  UG_PutString (0, 26, buf);

  strcpy(str,"CV");
  snprintf (buf, sizeof buf, "Mode: %s, Temp: %2.1fC", str, p->temp_c);
  UG_PutString (0, 37, buf);

  if (top_voltage_limit < 8.0) {
    snprintf (buf, sizeof buf, "Vin:%3.2f, ERR: V INPUT LOW!!", p->Vin);
  }
  else {
    snprintf (buf, sizeof buf, "Vin:%3.1fV, Output: %s %d", p->Vin,
              (p->output_state) ? "On," : "Off,", p->ticks);
  }
  UG_PutString (0, 49, buf);
//  oled_update_ssd1322 ();
}

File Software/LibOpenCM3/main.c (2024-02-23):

/* main.c : Lab Power Supply
 */

#include <stdio.h>
#include <stdlib.h>
#include <string.h>
#include <stdbool.h>
#include <ctype.h>
#include <stdint.h>

#include <libopencm3/stm32/rcc.h>
#include <libopencm3/stm32/gpio.h>
#include <libopencm3/stm32/adc.h>
#include <libopencm3/stm32/spi.h>
#include <libopencm3/stm32/exti.h>
#include <libopencm3/stm32/iwdg.h>
#include <libopencm3/cm3/nvic.h>
#include <libopencm3/cm3/systick.h>
#include <libopencm3/cm3/scb.h>

#include "FreeRTOS.h"
#include "task.h"
#include "semphr.h"
#include "mcuio.h"
#include "miniprintf.h"

#include "ugui.h"
#include "oled_drv.h"
#include "i2c.h"
#include "mcp23017.h"
#include "main.h"
#include "led_drv.h"
#include "gcvt_2.h"
#include "at42qt1070.h"
#include "mcp9808.h"

// #define USE_USB 1
// #define TASK_TRACE 1
#define ENABLE_WDT 1

// TO DO
// 1. Add watch dog timer support. Done
// 2. flash mem buttons. Done
// 3. check stack space. Done
// 4. check program size. Done.
// 5. use struture instend of globals
// 6. over-sample and filter ADC results, Done but not sure if its useful
// 7. optimize OLED, run faster, update only delta lines
// 8. use the voltmeter to auto adjust the PS output setting
// 9. Test zero setting. Looks ok but some time jumps to 1.7 volts. Done
// 10. Add encoder range support. Done
// 11. Add start up splash screen. Done
// 12. make presets adjustable, 5V and 3.3 V. Done
// 13. boot up diag. Done
// 14. Fix OLED start up problem. Done
// 15. Add remote calibrate function. Done
// 16. Add program and heap size dump. Done
// 17. How to measure noise??
// 18. Add memory preset adjustment support.
// 19. When output is off, set V out to zero so out show zero volts. Higher drive voltage?
// 20. Use 1 precent resitors for Vin divider.
// 21. remove old switch code. Done
// 22. Limit top output so its gracefull. Done
// 23. Build diff amp to measure switcher ripple
// 24. Add boot up diag, i2c checks, etc

// indent -gnu -br -cli2 -lp -nut -l100 main.c
// sudo gtkterm --port /dev/ttyACM0

#define GPIO_PORT_OUT_ENB	GPIOB
#define GPIO_OUT_ENB		GPIO12

#define GPIO_PORT_CURRENT_LIMIT_IN   GPIOB
#define GPIO_PIN_CURRENT_LIMIT_IN    GPIO13  // #define GPIO13 (1 << 13)

parameters_t param = {
  0.0, // v_out;
  0.0, // i_out;
  0.0, // v_set;
  0.0, // i_set;
  0.0, // p_out;
  0.0, // v_in;
  0.0, // heatsink_temp;
  0.0, // cpu_temp;  
  0.0, // mem1_v_set;
  0.0, // mem2_v_set;

  0, // mode;
  0, // out_on;
  0, // lock;  
  0, // ticks;  
};

I2C_Control i2c_handle;         // I2C Control struct
TaskHandle_t sw_debouce_taskHandle = NULL;
TaskHandle_t oled_task_Handle = NULL;
static SemaphoreHandle_t i2c_mutex;

static volatile bool show_rx = true;    // false;
float mcp9808_float_temp = 0.0;
char mcp9808_str[20] = "x.x";
char Vin_str[30] = "0.0"; 
char Vtop_str[30] = "12.0";
#define REGULATOR_DROP (3.0)
float top_voltage_limit = 15.00;  // This should be calculated from input voltage

int v_dac_set = 0;
int i_dac_set = 0;

#define MEM1_VOLTAGE_PRESET 3.3 // was 3.3
#define MEM1_CURRENT_PRESET 1.2

#define MEM2_VOLTAGE_PRESET 5.0
#define MEM2_CURRENT_PRESET 1.5

float mem1_voltage_preset = MEM1_VOLTAGE_PRESET;        // normally 3.3 volts
float mem1_current_preset = MEM1_CURRENT_PRESET;        // normally 3.3 volts

float mem2_voltage_preset = MEM2_VOLTAGE_PRESET;
float mem2_current_preset = MEM2_CURRENT_PRESET;

float last_voltage_preset = 0.0;
volatile TickType_t mem1_press_time = 0;        // for xTaskGetTickCount ();
volatile TickType_t mem2_press_time = 0;

uint32_t output_state = 0;
uint32_t mem1_state = 0;
uint32_t mem2_state = 0;

typedef struct _cursor
{
  int cursor_on;
  int position;
  int multi;
} cursor_t;

cursor_t cursor_voltage = {
  0,                            // cursor cursor_on
  0,                            // cursor position
  1                             // cursor multi
};

cursor_t cursor_current = {
  0,                            // cursor cursor_on
  0,                            // cursor position
  1                             // cursor multi
};

int voltage_cursor_on = 0;
int voltage_position = 0;
int voltage_multi = 1;

int current_cursor_on = 0;
int current_position = 0;
int current_multi = 1;

mov_avg_t volts_mov_avg;
mov_avg_t current_mov_avg;

int show_status_flag = 0;
int log_interval = 10;
int debug_flag = 0;

int program_bytes = 0;
static const char pOFF[] = { "OFF" };
static const char pCV[] = { "CV" };
static const char pCC[] = { "CC" };

const char *mode_str = pOFF;

uint8_t V_RotaryCurrentState = 0x00;
uint8_t V_RotaryTransition = 0;
int V_RotaryPosition = 0;
int V_RotaryPosition_last = 0;
uint8_t I_RotaryCurrentState = 0x00;
uint8_t I_RotaryTransition = 0;
int I_RotaryPosition = 0;
int I_RotaryPosition_last = 0;

int flash_stack_size = 0;
int console_stack_size = 0;
int bounce_stack_size = 0;
int oled_stack_size = 0;

void
millisecs_sleep (uint64_t ms)
{
  volatile TickType_t start = xTaskGetTickCount ();

  while (ms < (xTaskGetTickCount () - start));
}

void
vApplicationTickHook (void)     // 1 millsecond tick
{
//  gpio_toggle (GPIOC, GPIO12);
}

void
wait_til_usb_ready (void)
{
  while (!usb_ready ()) {
    vTaskDelay (pdMS_TO_TICKS (100));
  }
}

/*********************************************************************
 * Lock mutex:
 *********************************************************************/
void
mutex_lock (void)
{
  xSemaphoreTake (i2c_mutex, (TickType_t) 10);
}

/*********************************************************************
 * Unlock mutex:
 *********************************************************************/
void
mutex_unlock (void)
{
  xSemaphoreGive (i2c_mutex);
}

 // https://electronics.stackexchange.com/questions/99915/stm32-rotary-encoder-with-hardware-interrupts
static const int8_t enc_states[] = { 0, -1, 1, 0, 1, 0, 0, -1, -1, 0, 0, 1, 0, 1, -1, 0 };

// level irq ?? https://electronics.stackexchange.com/questions/158749/how-to-use-level-triggered-interrupts-with-stm32f1xx
// Does not appear to be support for level interrupts in stm32f1
static void
exti_setup (void)
{
  /* Enable GPIOB clock. */
  rcc_periph_clock_enable (RCC_GPIOB);

  /* Enable AFIO clock. */
  rcc_periph_clock_enable (RCC_AFIO);

  /* Enable EXTI0 interrupt. */
  nvic_enable_irq (NVIC_EXTI0_IRQ);

  /* Set GPIO1 (in GPIO port B) to 'input float'. */
  gpio_set_mode (GPIOB, GPIO_MODE_INPUT, GPIO_CNF_INPUT_FLOAT, GPIO0);

  /* Configure the EXTI 0 subsystem. */
  exti_select_source (EXTI0, GPIOB);

//  exti_set_trigger (EXTI0, EXTI_TRIGGER_RISING);  // does not trigger
//  exti_set_trigger (EXTI0, EXTI_TRIGGER_FALLING); // shoudl be best choice
  exti_set_trigger (EXTI0, EXTI_TRIGGER_BOTH);  // was used a lot
  exti_enable_request (EXTI0);
}

//  https://www.freertos.org/taskresumefromisr.html
//  https://www.freertos.org/RTOS_Task_Notification_As_Counting_Semaphore.html
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

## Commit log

2020-10-19 inital commit
    [configuration.h]
2020-10-27 add hardware projects
    [Comonents.SchLib, Pick Place for lps_display_rev_10.csv, Schlib1.SchLib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]
2020-10-28 clean up
    [Comonents.SchLib, Pick Place for lps_display_rev_10.csv, Schlib1.SchLib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]
2020-10-28 add hw library and display hw
    [Comonents.SchLib, Pick Place for lps_display_rev_10.csv, Schlib1.SchLib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]
2024-02-23 code clean up and add kicad hw work
    [Comonents.SchLib, Pick Place for lps_display_rev_10.csv, Schlib1.SchLib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]
2024-02-28 add current reg sch
    [lps_regulator.SCHLIB, lps_regulator_3.SCHLIB, lps_regulator_3.step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]
2024-03-27 add stm32 cude support
2024-03-27 add stm32 cube support
